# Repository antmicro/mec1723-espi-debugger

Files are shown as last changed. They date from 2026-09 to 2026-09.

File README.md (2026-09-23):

# MEC1723 eSPI Debugger

Copyright (c) 2026 [Antmicro](https://www.antmicro.com)

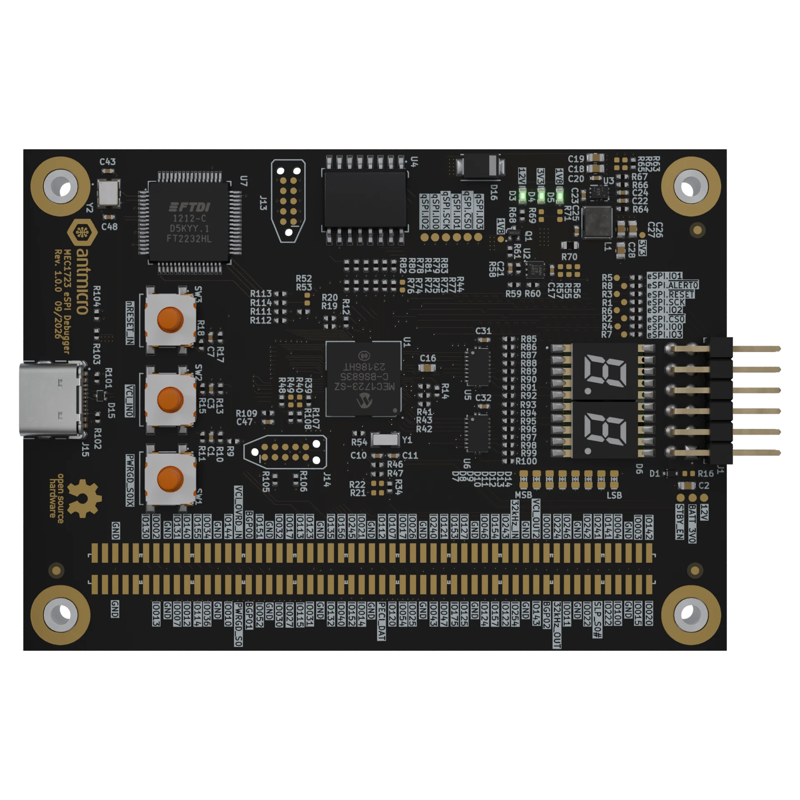
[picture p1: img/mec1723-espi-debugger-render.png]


## Overview

This project contains open hardware design files for a debug board based on Microchip MEC1723 embedded controller which includes ARM Cortex-M4 core and eSPI physical interface.
The board is designed to aid development, bring-up and integration of eSPI-based data link between servers (HPMs) and Data Center Secure Control Modules (DC-SCMs).
The board has a 0.1 inch pin header connector which allows to connect it to the eSPI bus in the system under development.
The board provides USB-accessible UART and JTAG interfaces, Port 80 status display and local flash storage for the MEC1723 firmware.
MEC1723 controllers are supported in [Zephyr](https://www.zephyrproject.org/) RTOS

The PCB design files were prepared in KiCad 10.x.

## Key features

* Microchip [MEC1723](https://www.microchip.com/en-us/product/mec1723) embedded controller with ARM Cortex-M4 and eSPI interface
* Generic 0.1 inch pinhead connector
* USB-C port with FTDI FT2232H USB interface bridge
* UART and JTAG interfaces accessible from the USB interface bridge
* 1 Gb QSPI NOR Flash for MEC1723 firmware storage
* Port 80 (POST code) display with dual seven-segment LED indicator
* Tag-Connect headers for debug and programming access
* 62 x 87 mm (2.44 x 3.42 inch) PCB outline

## Project structure

The main directory contains KiCad PCB project files, the LICENSE, and this README, and the img directory contains graphics for this README.

## License

This project is licensed under the [Apache-2.0](LICENSE) license.

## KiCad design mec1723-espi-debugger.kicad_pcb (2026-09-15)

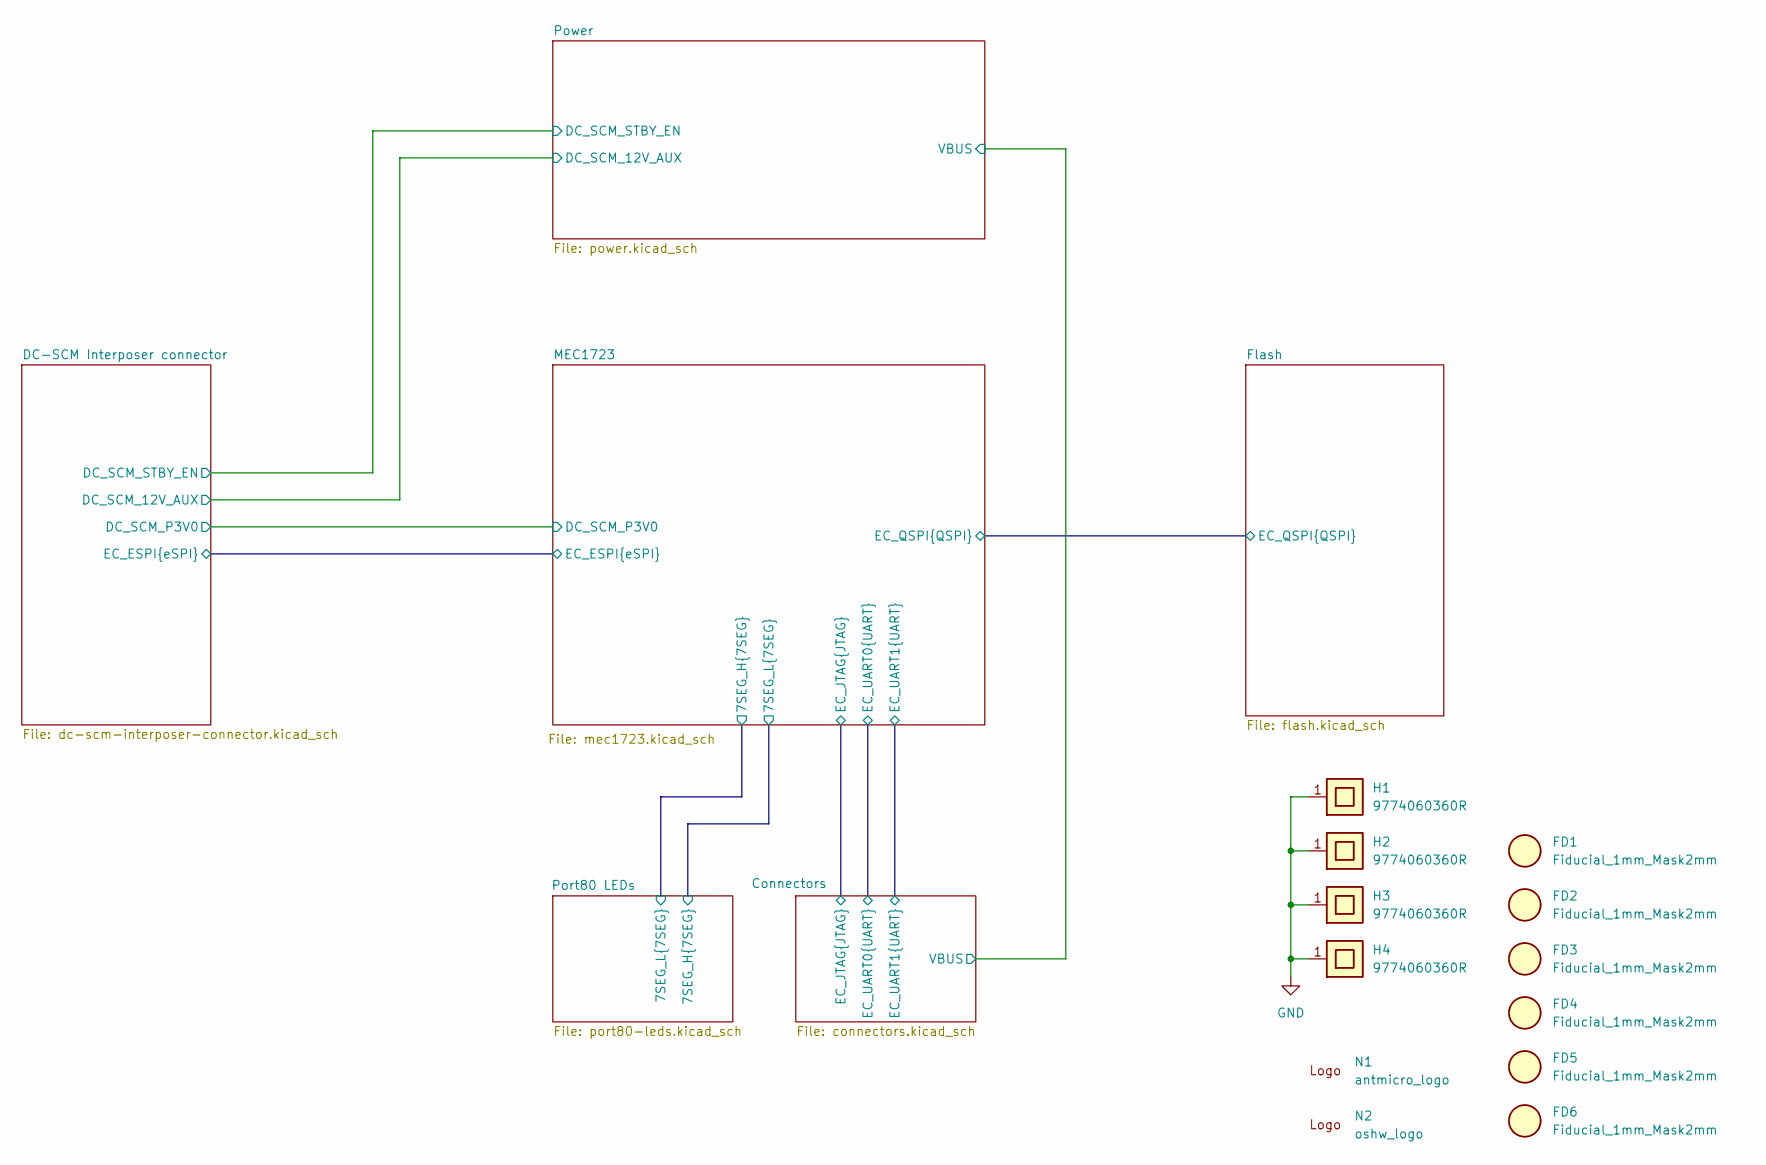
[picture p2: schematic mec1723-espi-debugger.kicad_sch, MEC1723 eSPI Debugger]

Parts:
FD1, FD2, FD3, FD4, FD5, FD6: Fiducial_1mm_Mask2mm
H1, H2, H3, H4: Spacer_Drill4.4mm_H6mm_9774060360R; MPN 9774060360R
N1: antmicro_logo; antmicro-logo_scaled_12mm
N2: oshw_logo; oshw-logo

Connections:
GND: H1.1, H2.1, H3.1, H4.1; also elsewhere on the board

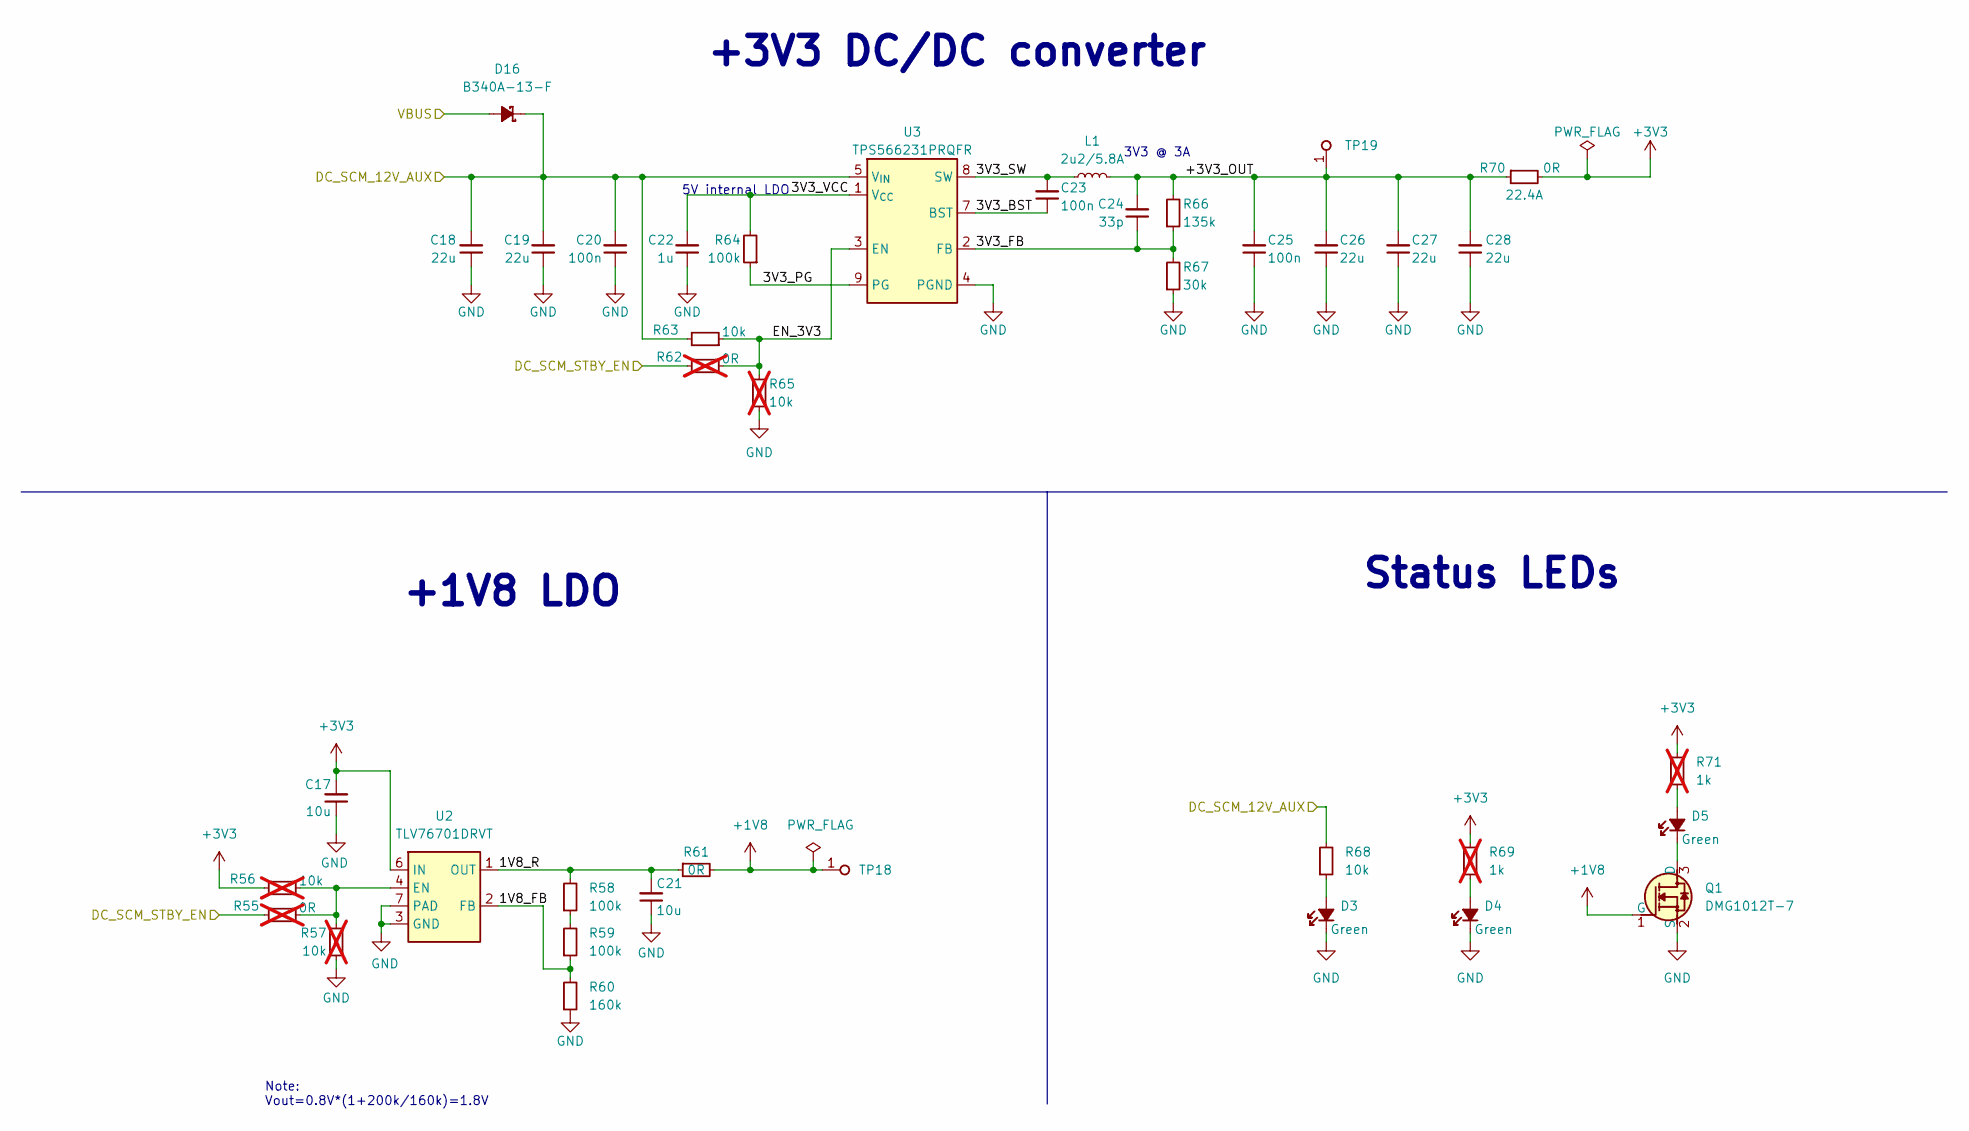
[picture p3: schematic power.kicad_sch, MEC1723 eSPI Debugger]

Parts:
C17, C21: C_10u_10V_0402; C_0402_1005Metric; Voltage 10V; MPN GRM155R61A106ME11D
C18, C19, C26, C27, C28: C_22u_16V_0603; C_0603_1608Metric_EIA; Voltage 16V; MPN CL10A226MO7JZNC
C20, C23, C25: C_100n_0402; C_0402_1005Metric; Voltage 50V; MPN GRM155R61H104KE14D
C22: C_1u_25V_0402; C_0402_1005Metric; Voltage 25V; MPN GRM155R61E105KE11J
C24: C_33p_0402; C_0402_1005Metric; MPN 04025A330FAT2A
D3, D4, D5: LED_G_0603_LTST-C190GKT; LED_0603_1608Metric_G; MPN LTST-C190GKT
D16: B340A-13-F; D_SMA; MPN B340A-13-F
L1: L_2u2_5.8A_WE-PMFI-35329222; L_WE-PMFI-353220; MPN 74479335329222
Q1: DMG1012T-7; SOT-523; MPN DMG1012T-7
R55, R62: R_0R_0402; R_0402_1005Metric; MPN ERJ2GE0R00X; not fitted
R56, R57, R65: R_10k_0402; R_0402_1005Metric; Tolerance 1%; MPN CR0402-FX-1002GLF; not fitted
R58, R59, R64: R_100k_0402; R_0402_1005Metric; Tolerance 1%; MPN CR0402-FX-1003GLF
R60: R_160k_0402; R_0402_1005Metric; Tolerance 1%; MPN CR0402-FX-1603GLF
R61: R_0R_0402; R_0402_1005Metric; MPN ERJ2GE0R00X
R63, R68: R_10k_0402; R_0402_1005Metric; Tolerance 1%; MPN CR0402-FX-1002GLF
R66: R_135k_0402; R_0402_1005Metric; Tolerance 0.1%; MPN RT0805BRD07135KL
R67: R_30k_0402; R_0402_1005Metric; Tolerance 1%; MPN CR0402-FX-3002GLF
R69, R71: R_1k_0402; R_0402_1005Metric; Tolerance 1%; MPN CR0402-FX-1001GLF; not fitted
R70: R_0R_22.4A_0603; R_0603_1608Metric; Tolerance template_tolerance; MPN PMR03EZPJ000
TP18, TP19: TP_0.75mm_SMD; TP_SMD_0.75mm
U2: TLV76701_WSON; WSON-6-1EP_2x2mm_P0.65mm; MPN TLV76701DRVT
U3: TPS566231P; VQFN-HR-9_2x1.5mm; MPN TPS566231PRQFR

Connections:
+1V8: Q1.1 (G), R61.2, TP18.1 (1_1); also elsewhere on the board
+3V3: C17.2, R56.2, R69.2, R70.2, R71.2, U2.6 (IN); also elsewhere on the board
/Connectors/VBUS: D16.2 (A); also elsewhere on the board
/DC-SCM Interposer connector/DC_SCM_12V_AUX: C18.2, C19.2, C20.2, D16.1 (C), R63.2, R68.2, U3.5 (V_{IN}), U3.6 (V_{IN}); also elsewhere on the board
/DC-SCM Interposer connector/DC_SCM_STBY_EN: R55.1, R62.1; also elsewhere on the board
/Power/1V8_FB: R59.1, R60.2, U2.2 (FB)
/Power/1V8_R: C21.2, R58.2, R61.1, U2.1 (OUT)
/Power/3V3_BST: C23.1, U3.7 (BST)
/Power/3V3_FB: C24.1, R66.1, R67.2, U3.2 (FB)
/Power/3V3_PG: R64.1, U3.9 (PG)
/Power/3V3_SW: C23.2, L1.1, U3.8 (SW)
/Power/3V3_VCC: C22.2, R64.2, U3.1 (V_{CC})
/Power/+3V3_OUT: C24.2, C25.2, C26.2, C27.2, C28.2, L1.2, R66.2, R70.1, TP19.1 (1_1)
/Power/EN_3V3: R62.2, R63.1, R65.2, U3.3 (EN)
GND: C17.1, C18.1, C19.1, C20.1, C21.1, C22.1, C25.1, C26.1, C27.1, C28.1, D3.1 (C), D4.1 (C), Q1.2 (S), R57.1, R60.1, R65.1, R67.1, U2.3 (GND), U2.5 (GND), U2.7 (PAD), U3.4 (PGND); also elsewhere on the board
unnamed: D3.2 (A), R68.1
unnamed: D4.2 (A), R69.1
unnamed: D5.2 (A), R71.1
unnamed: D5.1 (C), Q1.3 (D)
unnamed: R58.1, R59.2
unnamed: R55.2, R56.1, R57.2, U2.4 (EN)

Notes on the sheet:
Note: Vout=0.8V*(1+200k/160k)=1.8V
Status LEDs
+1V8 LDO
3V3 @ 3A
5V internal LDO
+3V3 DC/DC converter

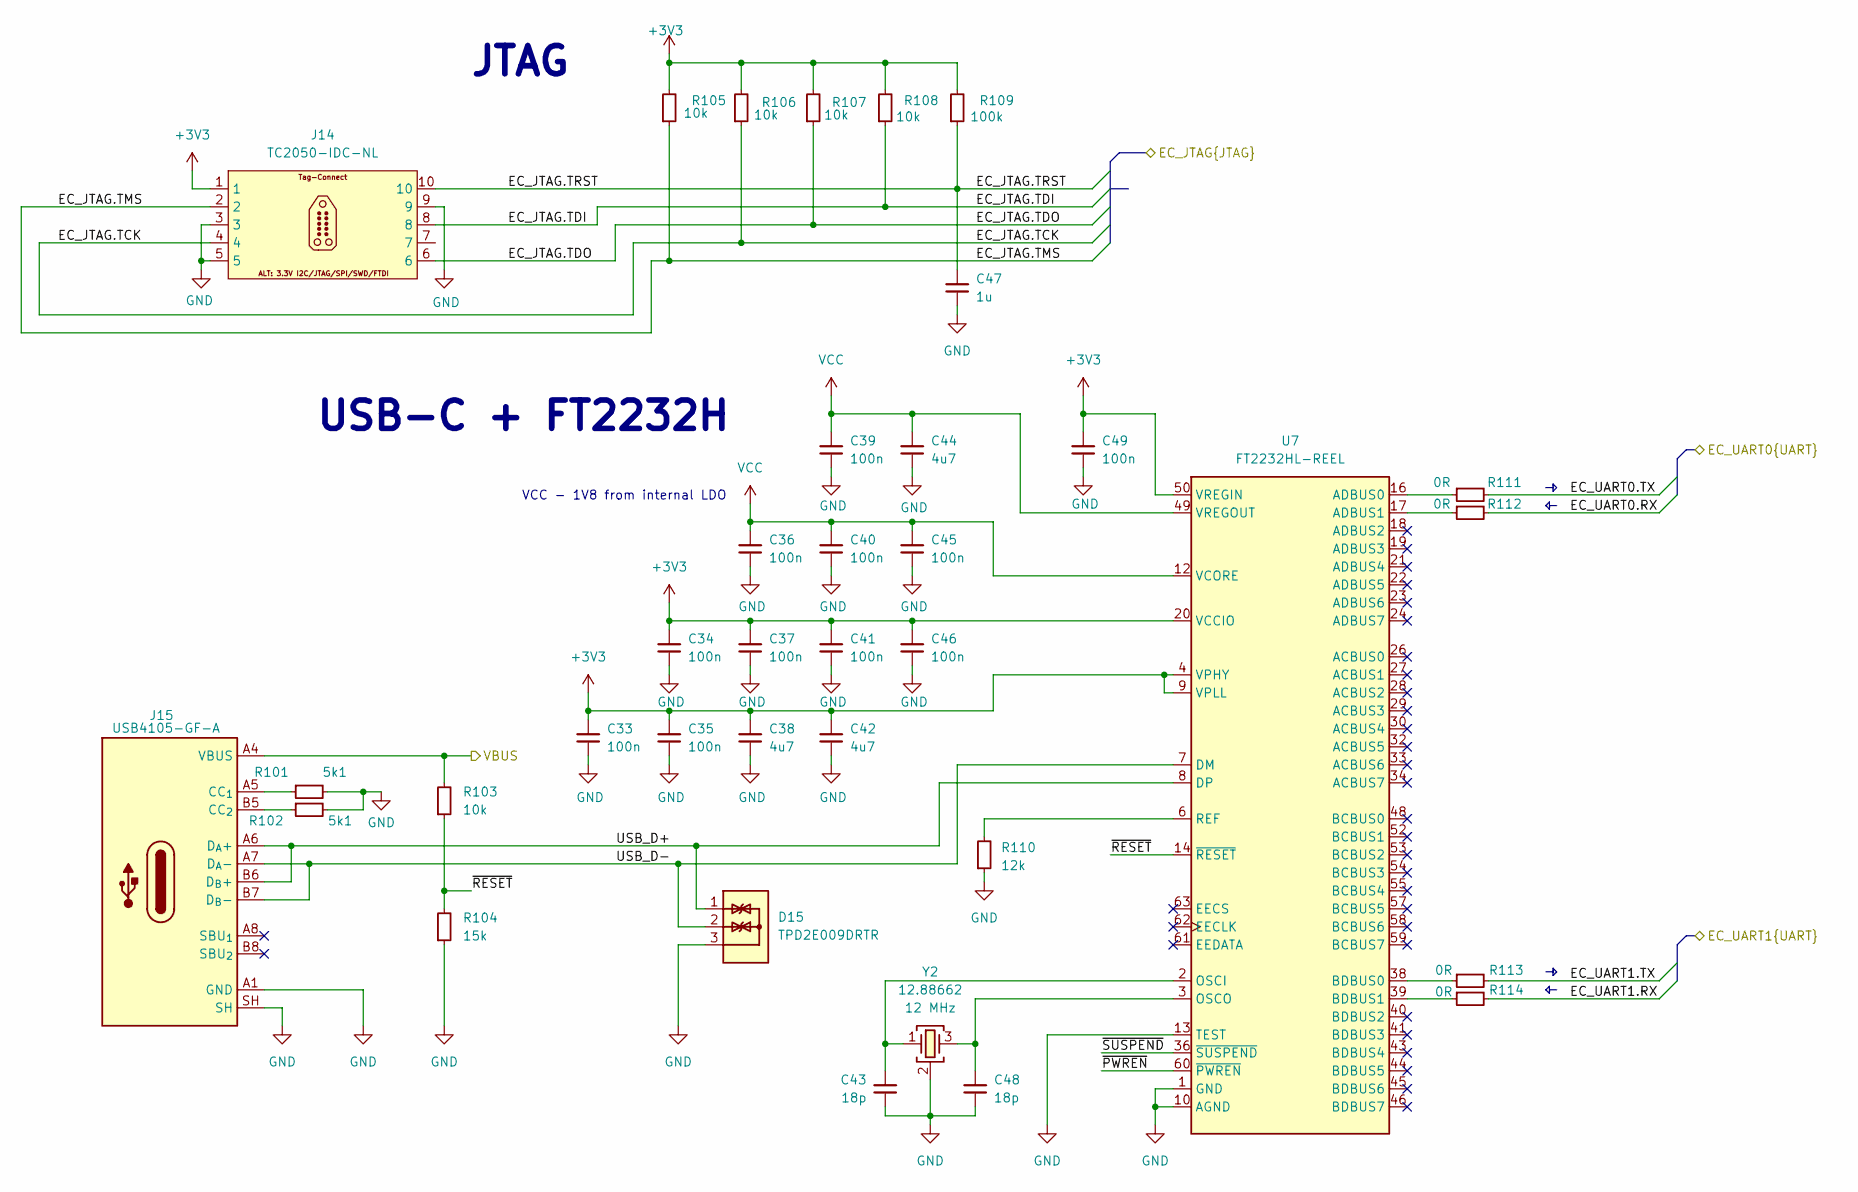
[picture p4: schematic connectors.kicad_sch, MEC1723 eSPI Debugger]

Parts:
C33, C34, C35, C36, C37, C39, C40, C41, C45, C46, C49: C_100n_16V_X7R_0402; C_0402_1005Metric; Voltage 16V; MPN C0402C104J4RAC7411
C38, C42, C44: C_4u7_10V_X7T_0402; C_0402_1005Metric; Voltage 10V; MPN GRM155D71A475ME15D
C43, C48: C_18p_0402; C_0402_1005Metric; MPN CL05C180JB51PNC
C47: C_1u_0402; C_0402_1005Metric; MPN C1005X6S1A105K050BC
D15: TPD2E009_SOT-9X3; SOT-723; MPN TPD2E009DRTR
J14: Tag-Connect_TC2050-IDC-NL_2x5_P1.27mm; MPN TC2050-IDC-NL
J15: USB-C_GCT_USB4105-GF-A; USB-C_Receptacle_GCT_USB4105-GF-A; MPN USB4105-GF-A
R101, R102: R_5k1_0402; R_0402_1005Metric; Tolerance 1%; MPN CR0402-FX-5101GLF
R103, R105, R106, R107, R108: R_10k_0402; R_0402_1005Metric; Tolerance 1%; MPN CR0402-FX-1002GLF
R104: R_15k_0402; R_0402_1005Metric; Tolerance 1%; MPN CR0402-FX-1502GLF
R109: R_100k_0402; R_0402_1005Metric; Tolerance 1%; MPN CR0402-FX-1003GLF
R110: R_12k_0402; R_0402_1005Metric; Tolerance 1%; MPN CR0402-FX-1202GLF
R111, R112, R113, R114: R_0R_0402; R_0402_1005Metric; MPN ERJ2GE0R00X
U7: FT2232HL-REEL; LQFP-64_10x10mm_P0.5mm; MPN FT2232HL-REEL
Y2: Resonator_12MHz_KX-7; Resonator_SMD_Geyer_KX-7_3.2x2.5x0.8mm; MPN 12.88662

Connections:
+3V3: C33.2, C34.2, C35.2, C37.2, C38.2, C41.2, C42.2, C46.2, C49.2, J14.1, R105.2, R106.2, R107.2, R108.2, R109.2, U7.4 (VPHY), U7.9 (VPLL), U7.20 (VCCIO), U7.31 (VCCIO), U7.42 (VCCIO), U7.50 (VREGIN), U7.56 (VCCIO); also elsewhere on the board
/Connectors/EC_JTAG.TCK: J14.4, R106.1; also elsewhere on the board
/Connectors/EC_JTAG.TDI: J14.8, R108.1; also elsewhere on the board
/Connectors/EC_JTAG.TDO: J14.6, R107.1; also elsewhere on the board
/Connectors/EC_JTAG.TMS: J14.2, R105.1; also elsewhere on the board
/Connectors/EC_JTAG.TRST: C47.2, J14.10, R109.1; also elsewhere on the board
/Connectors/EC_UART0.RX: R112.2; also elsewhere on the board
/Connectors/EC_UART0.TX: R111.2; also elsewhere on the board
/Connectors/EC_UART1.RX: R114.2; also elsewhere on the board
/Connectors/EC_UART1.TX: R113.2; also elsewhere on the board
/Connectors/USB_D+: D15.1, J15.A6 (D_{A}+), J15.B6 (D_{B}+), U7.8 (DP)
/Connectors/USB_D-: D15.2, J15.A7 (D_{A}-), J15.B7 (D_{B}-), U7.7 (DM)
/Connectors/VBUS: J15.A4 (VBUS), J15.A9 (VBUS), J15.B4 (VBUS), J15.B9 (VBUS), R103.2; also elsewhere on the board
/Connectors/~PWREN: U7.60 (~PWREN)
/Connectors/~RESET: R103.1, R104.2, U7.14 (~RESET)
/Connectors/~SUSPEND: U7.36 (~SUSPEND)
GND: C33.1, C34.1, C35.1, C36.1, C37.1, C38.1, C39.1, C40.1, C41.1, C42.1, C43.1, C44.1, C45.1, C46.1, C47.1, C48.1, C49.1, D15.3, J14.3, J14.5, J14.9, J15.A1 (GND), J15.A12 (GND), J15.B1 (GND), J15.B12 (GND), J15.SH, R101.2, R102.2, R104.1, R110.1, U7.1 (GND), U7.5 (GND), U7.10 (AGND), U7.11 (GND), U7.13 (TEST), U7.15 (GND), U7.25 (GND), U7.35 (GND), U7.47 (GND), U7.51 (GND), Y2.2 (SH), Y2.4 (SH); also elsewhere on the board
unnamed: J15.A5 (CC_{1}), R101.1
unnamed: J15.B5 (CC_{2}), R102.1
unnamed: R111.1, U7.16 (ADBUS0)
unnamed: R112.1, U7.17 (ADBUS1)
unnamed: R113.1, U7.38 (BDBUS0)
unnamed: R114.1, U7.39 (BDBUS1)
unnamed: C43.2, U7.2 (OSCI), Y2.1
unnamed: C48.2, U7.3 (OSCO), Y2.3
unnamed: R110.2, U7.6 (REF)
VCC: C36.2, C39.2, C40.2, C44.2, C45.2, U7.12 (VCORE), U7.37 (VCORE), U7.49 (VREGOUT), U7.64 (VCORE)

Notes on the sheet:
VCC - 1V8 from internal LDO
JTAG
USB-C + FT2232H

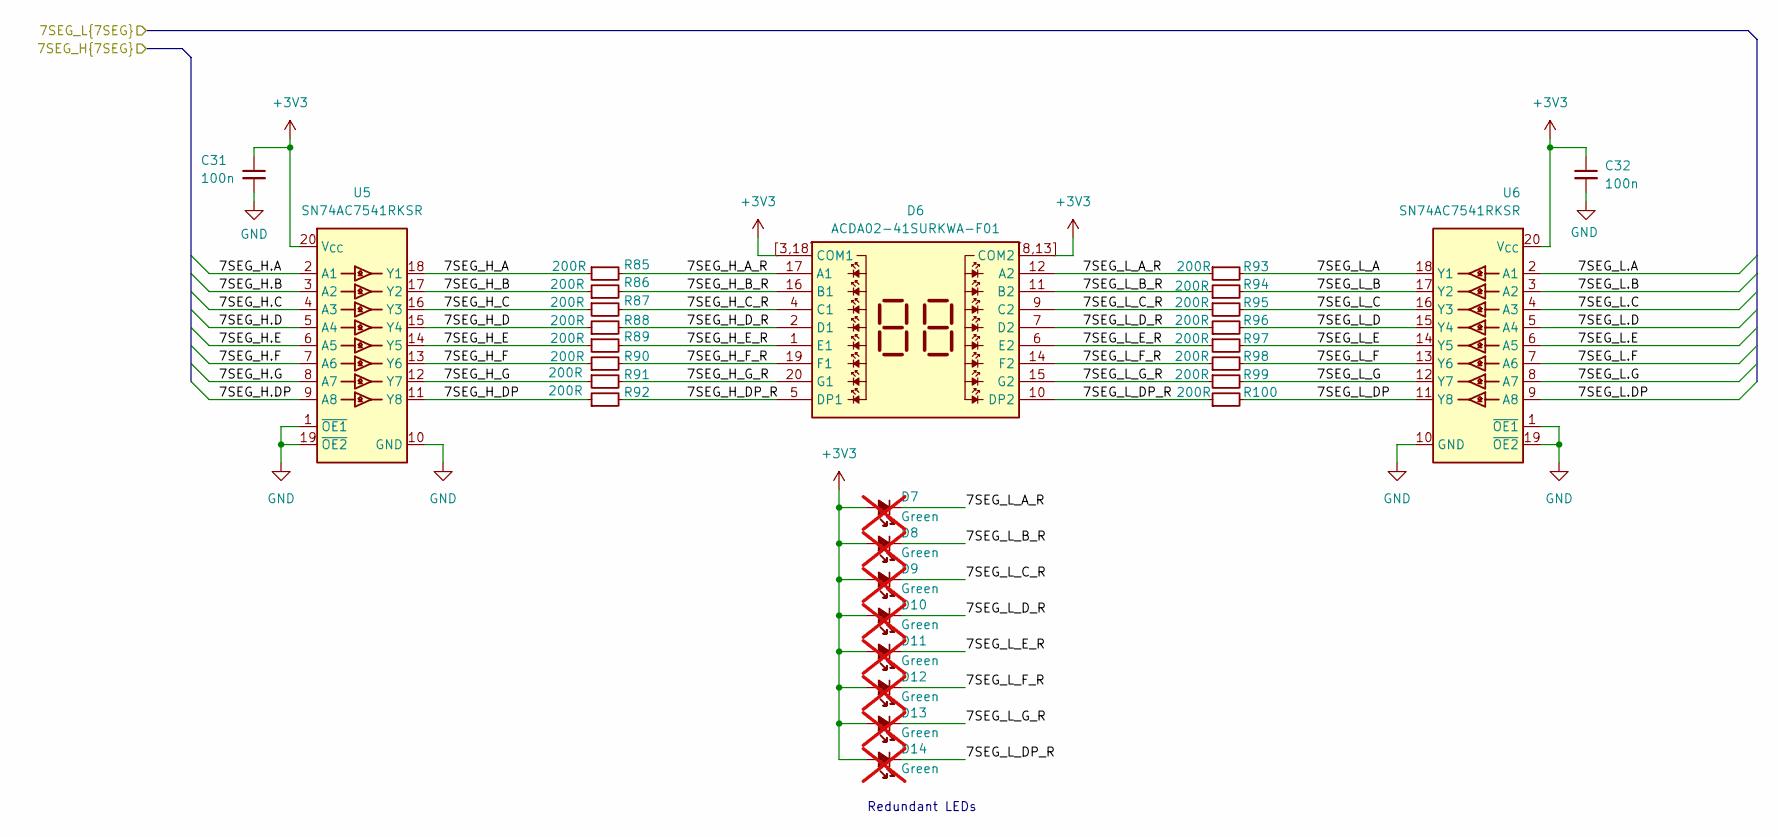
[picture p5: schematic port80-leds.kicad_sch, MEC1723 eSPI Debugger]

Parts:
C31, C32: C_100n_0402; C_0402_1005Metric; Voltage 50V; MPN GRM155R61H104KE14D
D6: ACDA02-41SURKWA-F01; MPN ACDA02-41SURKWA-F01
D7, D8, D9, D10, D11, D12, D13, D14: LED_G_0603_LTST-C190GKT; LED_0603_1608Metric_G; MPN LTST-C190GKT; not fitted
R85, R86, R87, R88, R89, R90, R91, R92, R93, R94, R95, R96, R97, R98, R99, R100: R_200R_0402; R_0402_1005Metric; Tolerance 1%; MPN CR0402-FX-2000GLF
U5, U6: SN74AC7541_VQFN; VQFN-20_1EP_4.5x2.5mm_P0.5mm; MPN SN74AC7541RKSR

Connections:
+3V3: C31.1, C32.1, D6.3 (COM1), D6.8 (COM2), D6.13 (COM2), D6.18 (COM1), D6.[3,18] (COM1), D6.[8,13] (COM2), D7.2 (A), D8.2 (A), D9.2 (A), D10.2 (A), D11.2 (A), D12.2 (A), D13.2 (A), D14.2 (A), U5.20 (V_{CC}), U6.20 (V_{CC}); also elsewhere on the board
/MEC1723/7SEG_H.A: U6.2 (A1); also elsewhere on the board
/MEC1723/7SEG_H.B: U6.3 (A2); also elsewhere on the board
/MEC1723/7SEG_H.C: U6.4 (A3); also elsewhere on the board
/MEC1723/7SEG_H.D: U6.5 (A4); also elsewhere on the board
/MEC1723/7SEG_H.DP: U6.9 (A8); also elsewhere on the board
/MEC1723/7SEG_H.E: U6.6 (A5); also elsewhere on the board
/MEC1723/7SEG_H.F: U6.7 (A6); also elsewhere on the board
/MEC1723/7SEG_H.G: U6.8 (A7); also elsewhere on the board
/MEC1723/7SEG_L.A: U5.2 (A1); also elsewhere on the board
/MEC1723/7SEG_L.B: U5.3 (A2); also elsewhere on the board
/MEC1723/7SEG_L.C: U5.4 (A3); also elsewhere on the board
/MEC1723/7SEG_L.D: U5.5 (A4); also elsewhere on the board
/MEC1723/7SEG_L.DP: U5.9 (A8); also elsewhere on the board
/MEC1723/7SEG_L.E: U5.6 (A5); also elsewhere on the board
/MEC1723/7SEG_L.F: U5.7 (A6); also elsewhere on the board
/MEC1723/7SEG_L.G: U5.8 (A7); also elsewhere on the board
/Port80 LEDs/7SEG_H_A: R85.1, U5.18 (Y1)
/Port80 LEDs/7SEG_H_A_R: D6.17 (A1), R85.2
/Port80 LEDs/7SEG_H_B: R86.1, U5.17 (Y2)
/Port80 LEDs/7SEG_H_B_R: D6.16 (B1), R86.2
/Port80 LEDs/7SEG_H_C: R87.1, U5.16 (Y3)
/Port80 LEDs/7SEG_H_C_R: D6.4 (C1), R87.2
/Port80 LEDs/7SEG_H_D: R88.1, U5.15 (Y4)
/Port80 LEDs/7SEG_H_DP: R92.1, U5.11 (Y8)
/Port80 LEDs/7SEG_H_DP_R: D6.5 (DP1), R92.2
/Port80 LEDs/7SEG_H_D_R: D6.2 (D1), R88.2
/Port80 LEDs/7SEG_H_E: R89.1, U5.14 (Y5)
/Port80 LEDs/7SEG_H_E_R: D6.1 (E1), R89.2
/Port80 LEDs/7SEG_H_F: R90.1, U5.13 (Y6)
/Port80 LEDs/7SEG_H_F_R: D6.19 (F1), R90.2
/Port80 LEDs/7SEG_H_G: R91.1, U5.12 (Y7)
/Port80 LEDs/7SEG_H_G_R: D6.20 (G1), R91.2
/Port80 LEDs/7SEG_L_A: R93.2, U6.18 (Y1)
/Port80 LEDs/7SEG_L_A_R: D6.12 (A2), D7.1 (C), R93.1
/Port80 LEDs/7SEG_L_B: R94.2, U6.17 (Y2)
/Port80 LEDs/7SEG_L_B_R: D6.11 (B2), D8.1 (C), R94.1
/Port80 LEDs/7SEG_L_C: R95.2, U6.16 (Y3)
/Port80 LEDs/7SEG_L_C_R: D6.9 (C2), D9.1 (C), R95.1
/Port80 LEDs/7SEG_L_D: R96.2, U6.15 (Y4)
/Port80 LEDs/7SEG_L_DP: R100.2, U6.11 (Y8)
/Port80 LEDs/7SEG_L_DP_R: D6.10 (DP2), D14.1 (C), R100.1
/Port80 LEDs/7SEG_L_D_R: D6.7 (D2), D10.1 (C), R96.1
/Port80 LEDs/7SEG_L_E: R97.2, U6.14 (Y5)
/Port80 LEDs/7SEG_L_E_R: D6.6 (E2), D11.1 (C), R97.1
/Port80 LEDs/7SEG_L_F: R98.2, U6.13 (Y6)
/Port80 LEDs/7SEG_L_F_R: D6.14 (F2), D12.1 (C), R98.1
/Port80 LEDs/7SEG_L_G: R99.2, U6.12 (Y7)
/Port80 LEDs/7SEG_L_G_R: D6.15 (G2), D13.1 (C), R99.1
GND: C31.2, C32.2, U5.1 (~OE1), U5.10 (GND), U5.19 (~OE2), U5.21 (GND), U6.1 (~OE1), U6.10 (GND), U6.19 (~OE2), U6.21 (GND); also elsewhere on the board

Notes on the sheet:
Redundant LEDs

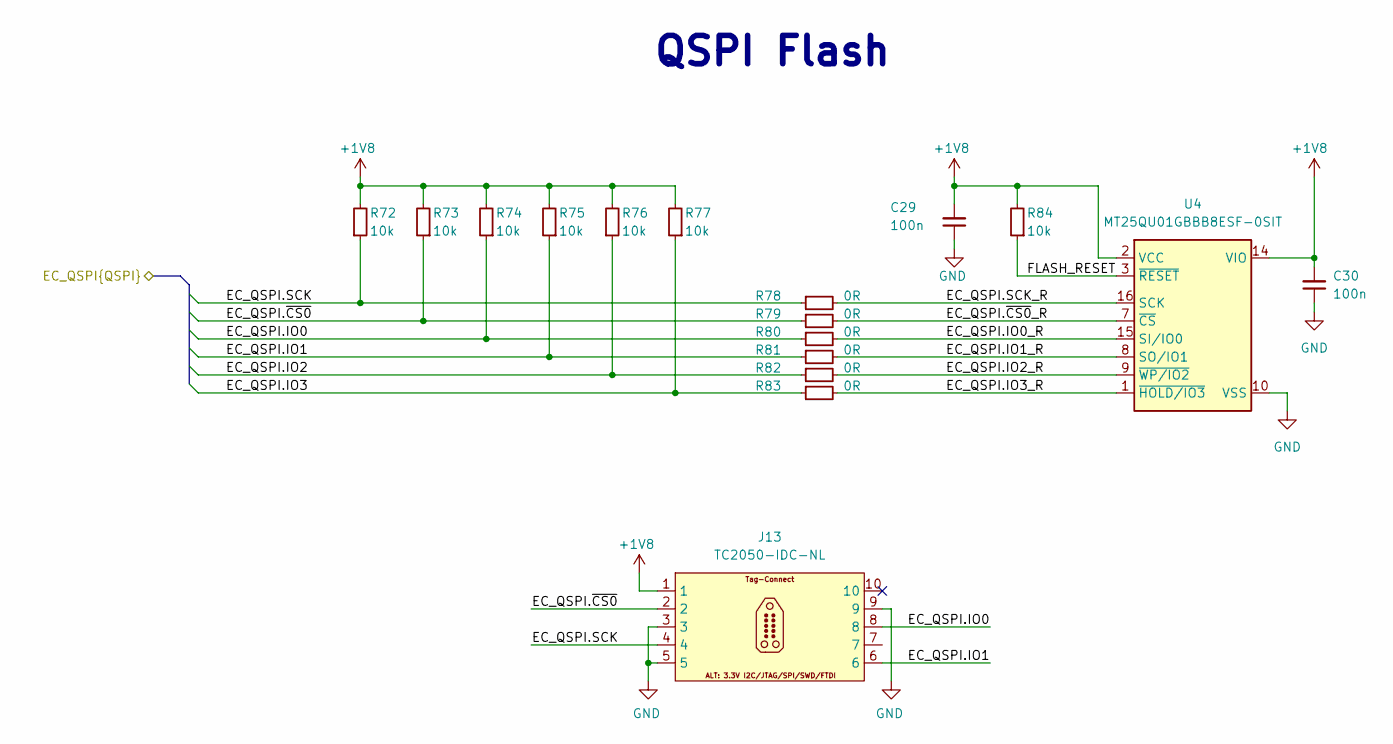
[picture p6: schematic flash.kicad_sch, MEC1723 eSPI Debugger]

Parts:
C29, C30: C_100n_0402; C_0402_1005Metric; Voltage 50V; MPN GRM155R61H104KE14D
J13: Tag-Connect_TC2050-IDC-NL_2x5_P1.27mm; MPN TC2050-IDC-NL
R72, R73, R74, R75, R76, R77, R84: R_10k_0402; R_0402_1005Metric; Tolerance 1%; MPN CR0402-FX-1002GLF
R78, R79, R80, R81, R82, R83: R_0R_0402; R_0402_1005Metric; MPN ERJ2GE0R00X
U4: MT25QU01GBBB8_SOIC; SOIC-16_W7.5mm; MPN MT25QU01GBBB8ESF-0SIT

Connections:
+1V8: C29.2, C30.2, J13.1, R72.2, R73.2, R74.2, R75.2, R76.2, R77.2, R84.2, U4.2 (VCC), U4.14 (VIO); also elsewhere on the board
/Flash/EC_QSPI.IO0: J13.8, R74.1, R80.1; also elsewhere on the board
/Flash/EC_QSPI.IO0_R: R80.2, U4.15 (SI/IO0)
/Flash/EC_QSPI.IO1: J13.6, R75.1, R81.1; also elsewhere on the board
/Flash/EC_QSPI.IO1_R: R81.2, U4.8 (SO/IO1)
/Flash/EC_QSPI.IO2: R76.1, R82.1; also elsewhere on the board
/Flash/EC_QSPI.IO2_R: R82.2, U4.9 (~WP/IO2)
/Flash/EC_QSPI.IO3: R77.1, R83.1; also elsewhere on the board
/Flash/EC_QSPI.IO3_R: R83.2, U4.1 (~HOLD/IO3)
/Flash/EC_QSPI.SCK: J13.4, R72.1, R78.1; also elsewhere on the board
/Flash/EC_QSPI.SCK_R: R78.2, U4.16 (SCK)
/Flash/EC_QSPI.~CS0: J13.2, R73.1, R79.1; also elsewhere on the board
/Flash/EC_QSPI.~CS0_R: R79.2, U4.7 (~CS)
/Flash/FLASH_RESET: R84.1, U4.3 (~RESET)
GND: C29.1, C30.1, J13.3, J13.5, J13.9, U4.10 (VSS); also elsewhere on the board

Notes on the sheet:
QSPI Flash

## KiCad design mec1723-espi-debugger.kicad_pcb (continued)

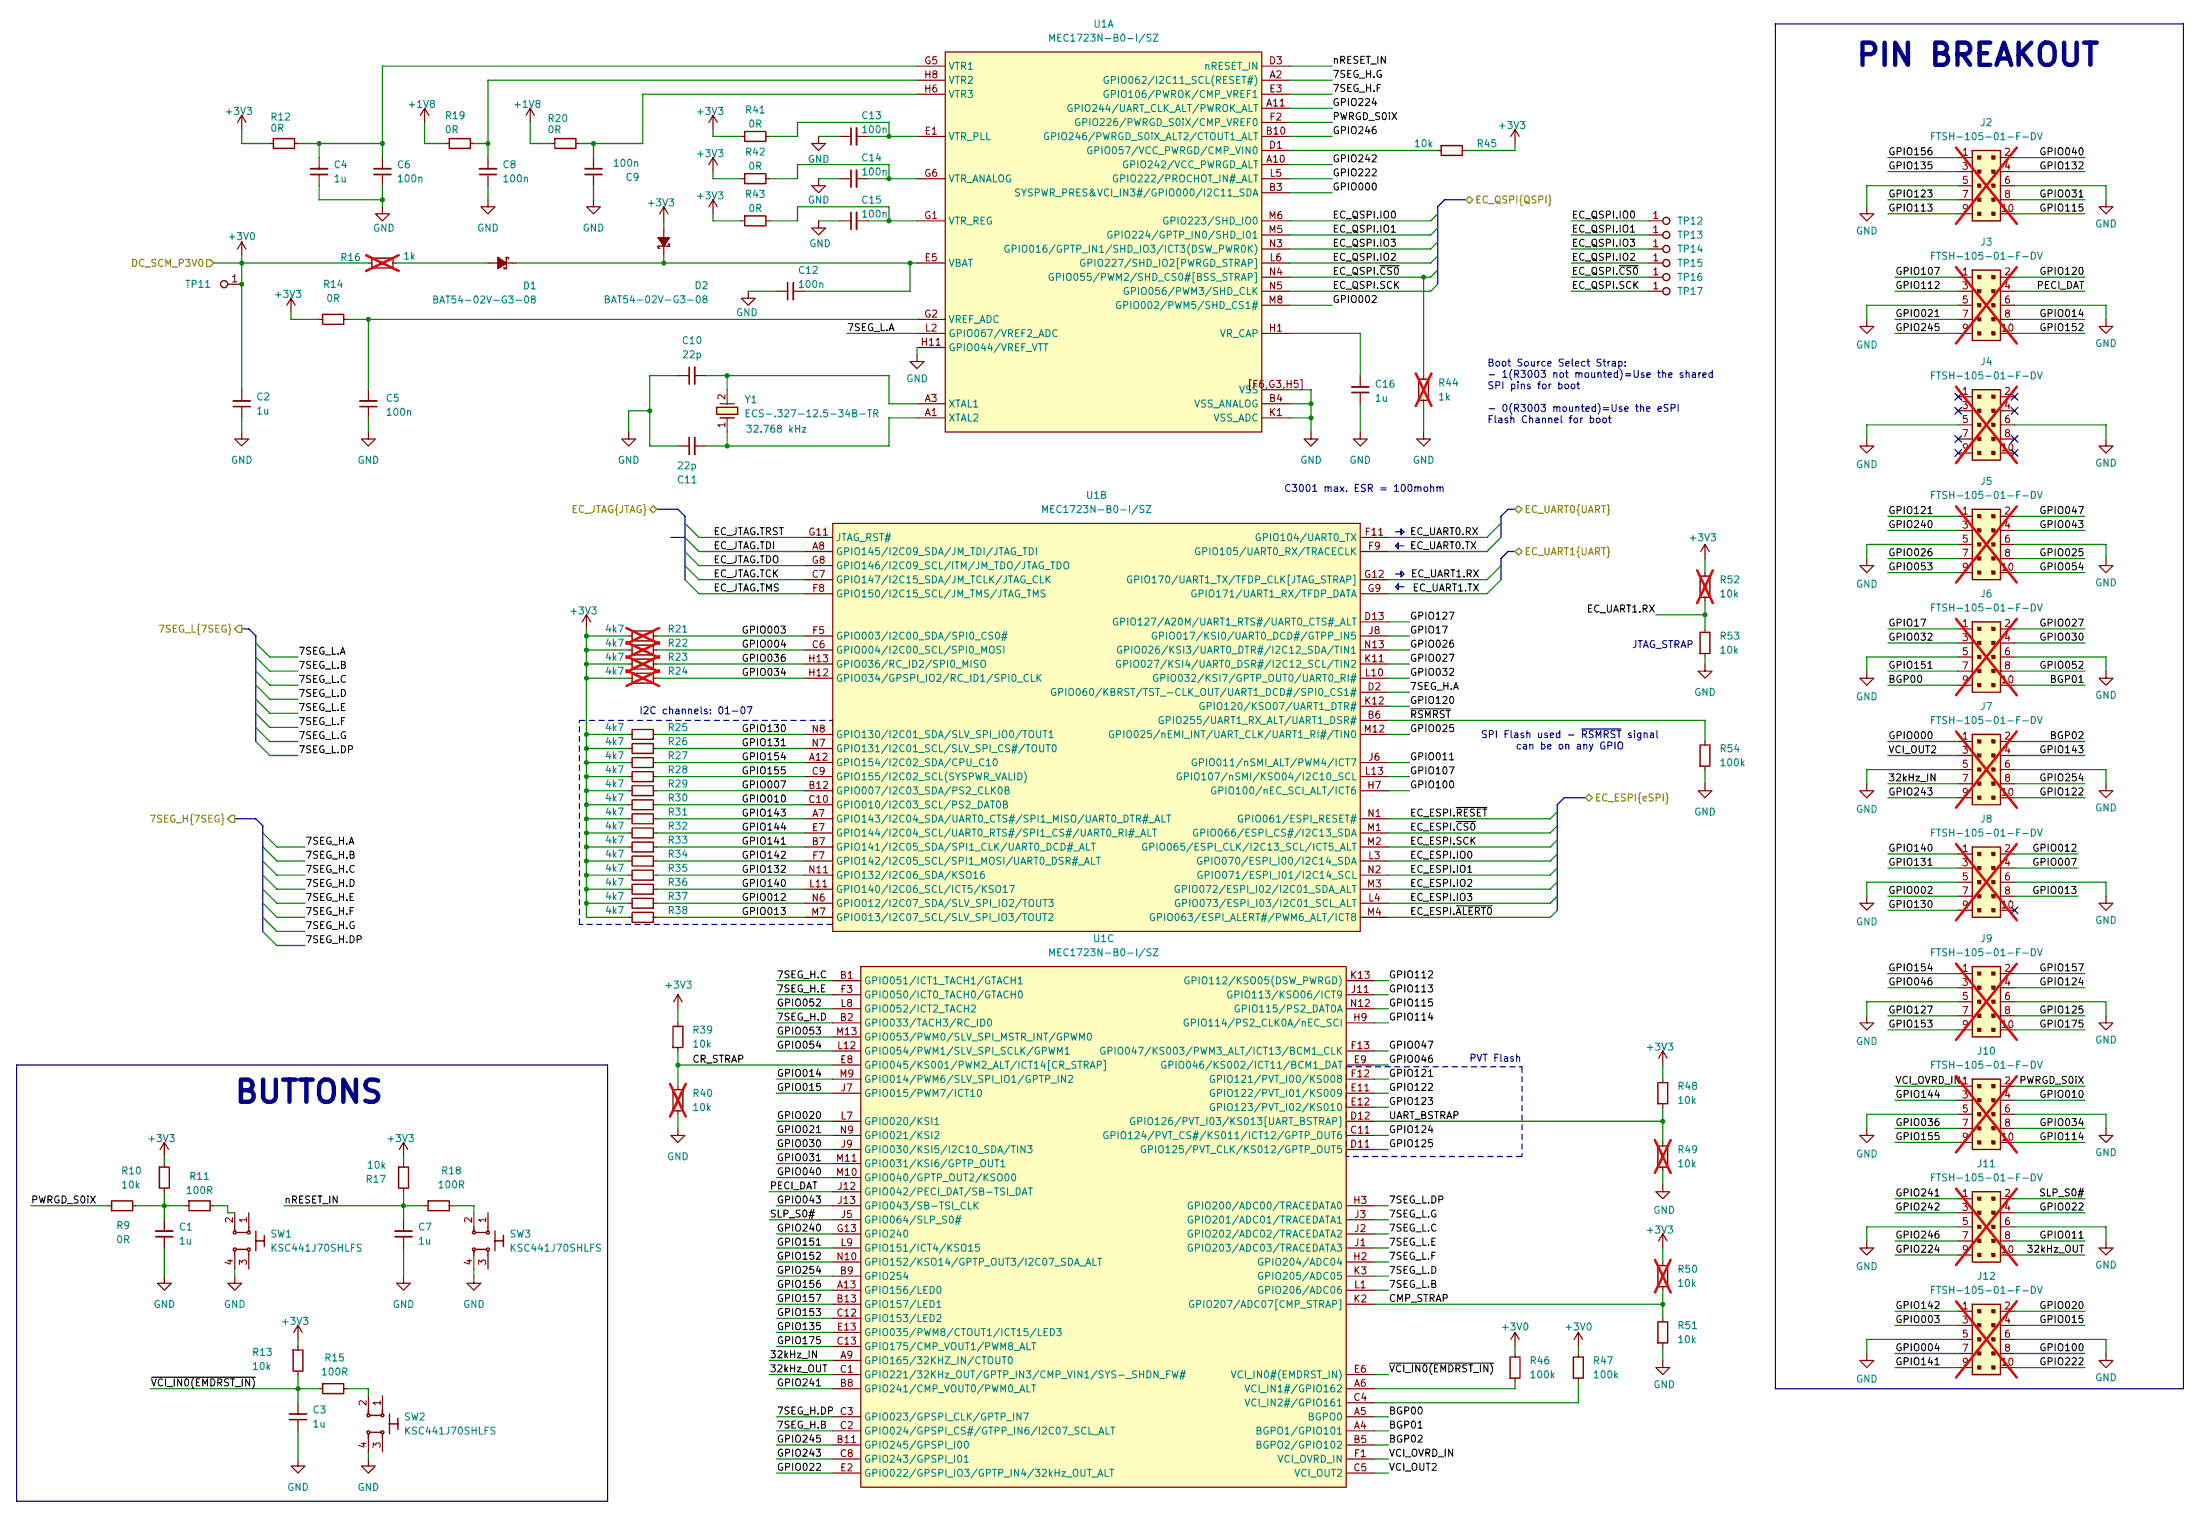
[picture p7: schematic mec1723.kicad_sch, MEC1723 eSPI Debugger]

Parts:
C1, C3, C7: C_1u_6.3V_X6S_0402; C_0402_1005Metric; Voltage 6.3V; MPN GRT155C80J105KE01D
C2, C4, C16: C_1u_0603; C_0603_1608Metric; MPN 0603YD105KAT2A
C5, C9, C12, C13, C14, C15: C_100n_0402; C_0402_1005Metric; Voltage 50V; MPN GRM155R61H104KE14D
C6, C8: C_100n_16V_X7R_0402; C_0402_1005Metric; Voltage 16V; MPN C0402C104J4RAC7411
C10, C11: C_22p_0402; C_0402_1005Metric; MPN CC0402JRNPO9BN220
D1, D2: BAT54-02V-G3-08; SOD-523; MPN BAT54-02V-G3-08
J2, J3, J4, J5, J6, J7, J8, J9, J10, J11, J12: PinHeader_2x5_P1.27mm_SMD; MPN FTSH-105-01-F-DV; not fitted
R9, R12, R14, R19, R20, R41, R42, R43: R_0R_0402; R_0402_1005Metric; MPN ERJ2GE0R00X
R10, R13, R17, R39, R45, R48, R51, R53: R_10k_0402; R_0402_1005Metric; Tolerance 1%; MPN CR0402-FX-1002GLF
R11, R15, R18: R_100R_0402; R_0402_1005Metric; Tolerance 1%; MPN CR0402-FX-1000GLF
R16, R44: R_1k_0402; R_0402_1005Metric; Tolerance 1%; MPN CR0402-FX-1001GLF; not fitted
R21, R22, R23, R24: R_4k7_0402; R_0402_1005Metric; Tolerance 1%; MPN CR0402-FX-4701GLF; not fitted
R25, R26, R27, R28, R29, R30, R31, R32, R33, R34, R35, R36, R37, R38: R_4k7_0402; R_0402_1005Metric; Tolerance 1%; MPN CR0402-FX-4701GLF
R40, R49, R50, R52: R_10k_0402; R_0402_1005Metric; Tolerance 1%; MPN CR0402-FX-1002GLF; not fitted
R46, R47, R54: R_100k_0402; R_0402_1005Metric; Tolerance 1%; MPN CR0402-FX-1003GLF
SW1, SW2, SW3: SW_KSC441J70SHLFS_SMD; MPN KSC441J70SHLFS
TP11, TP12, TP13, TP14, TP15, TP16, TP17: TP_1mm_SMD; TP_SMD_1mm
U1: MEC1723N-B0-I/SZ; BGA-169-144_9x9mm_Layout13x13_P0.7mm; MPN MEC1723N-B0-I/SZ
Y1: Resonator_32.768kHz_ECX-31B; Resonator_SMD_ECS_ECX-31B_3.2x1.5x0.9mm; MPN ECS-.327-12.5-34B-TR

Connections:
+1V8: R19.1, R20.1; also elsewhere on the board
+3V0: C2.2, R16.1, R46.2, R47.2, TP11.1 (1_1); also elsewhere on the board
+3V3: D2.2 (A), R10.1, R12.1, R13.1, R14.1, R17.1, R21.2, R22.2, R23.2, R24.2, R25.2, R26.2, R27.2, R28.2, R29.2, R30.2, R31.2, R32.2, R33.2, R34.2, R35.2, R36.2, R37.2, R38.2, R39.2, R41.1, R42.1, R43.1, R45.2, R48.2, R50.2, R52.2; also elsewhere on the board
/Connectors/EC_JTAG.TCK: U1.C7 (GPIO147/I2C15_SDA/JM_TCLK/JTAG_CLK); also elsewhere on the board
/Connectors/EC_JTAG.TDI: U1.A8 (GPIO145/I2C09_SDA/JM_TDI/JTAG_TDI); also elsewhere on the board
/Connectors/EC_JTAG.TDO: U1.G8 (GPIO146/I2C09_SCL/ITM/JM_TDO/JTAG_TDO); also elsewhere on the board
/Connectors/EC_JTAG.TMS: U1.F8 (GPIO150/I2C15_SCL/JM_TMS/JTAG_TMS); also elsewhere on the board
/Connectors/EC_JTAG.TRST: U1.G11 (JTAG_RST#); also elsewhere on the board
/Connectors/EC_UART0.RX: U1.F11 (GPIO104/UART0_TX); also elsewhere on the board
/Connectors/EC_UART0.TX: U1.F9 (GPIO105/UART0_RX/TRACECLK); also elsewhere on the board
/Connectors/EC_UART1.RX: R52.1, R53.2, U1.G12 (GPIO170/UART1_TX/TFDP_CLK[JTAG_STRAP]); also elsewhere on the board
/Connectors/EC_UART1.TX: U1.G9 (GPIO171/UART1_RX/TFDP_DATA); also elsewhere on the board
/DC-SCM Interposer connector/EC_ESPI.IO0: U1.L3 (GPIO070/ESPI_I00/I2C14_SDA); also elsewhere on the board
/DC-SCM Interposer connector/EC_ESPI.IO1: U1.N2 (GPIO071/ESPI_I01/I2C14_SCL); also elsewhere on the board
/DC-SCM Interposer connector/EC_ESPI.IO2: U1.M3 (GPIO072/ESPI_I02/I2C01_SDA_ALT); also elsewhere on the board
/DC-SCM Interposer connector/EC_ESPI.IO3: U1.L4 (GPIO073/ESPI_I03/I2C01_SCL_ALT); also elsewhere on the board
/DC-SCM Interposer connector/EC_ESPI.SCK: U1.M2 (GPIO065/ESPI_CLK/I2C13_SCL/ICT5_ALT); also elsewhere on the board
/DC-SCM Interposer connector/EC_ESPI.~ALERT0: U1.M4 (GPIO063/ESPI_ALERT#/PWM6_ALT/ICT8); also elsewhere on the board
/DC-SCM Interposer connector/EC_ESPI.~CS0: U1.M1 (GPIO066/ESPI_CS#/I2C13_SDA); also elsewhere on the board
/DC-SCM Interposer connector/EC_ESPI.~RESET: U1.N1 (GPIO061/ESPI_RESET#); also elsewhere on the board
/Flash/EC_QSPI.IO0: TP12.1 (1_1), U1.M6 (GPIO223/SHD_IO0); also elsewhere on the board
/Flash/EC_QSPI.IO1: TP13.1 (1_1), U1.M5 (GPIO224/GPTP_IN0/SHD_I01); also elsewhere on the board
/Flash/EC_QSPI.IO2: TP15.1 (1_1), U1.L6 (GPIO227/SHD_IO2[PWRGD_STRAP]); also elsewhere on the board
/Flash/EC_QSPI.IO3: TP14.1 (1_1), U1.N3 (GPIO016/GPTP_IN1/SHD_IO3/ICT3(DSW_PWR0K)); also elsewhere on the board
/Flash/EC_QSPI.SCK: TP17.1 (1_1), U1.N5 (GPIO056/PWM3/SHD_CLK); also elsewhere on the board
/Flash/EC_QSPI.~CS0: R44.2, TP16.1 (1_1), U1.N4 (GPIO055/PWM2/SHD_CS0#[BSS_STRAP]); also elsewhere on the board
/MEC1723/7SEG_H.A: U1.D2 (GPIO060/KBRST/TST_-CLK_OUT/UART1_DCD#/S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); also elsewhere on the board
/MEC1723/7SEG_H.B: U1.C2 (GPIO024/GPSPI_CS#/GTPP_IN6/I2C07_SCL_ALT); also elsewhere on the board
/MEC1723/7SEG_H.C: U1.B1 (GPIO051/ICT1_TACH1/GTACH1); also elsewhere on the board
/MEC1723/7SEG_H.D: U1.B2 (GPIO033/TACH3/RC_ID0); also elsewhere on the board
/MEC1723/7SEG_H.DP: U1.C3 (GPIO023/GPSPI_CLK/GPTP_IN7); also elsewhere on the board
/MEC1723/7SEG_H.E: U1.F3 (GPIO050/ICT0_TACH0/GTACH0); also elsewhere on the board
/MEC1723/7SEG_H.F: U1.E3 (GPIO106/PWROK/CMP_VREF1); also elsewhere on the board
/MEC1723/7SEG_H.G: U1.A2 (GPIO062/I2C11_SCL(RESET#)); also elsewhere on the board
/MEC1723/7SEG_L.A: U1.L2 (GPIO067/VREF2_ADC); also elsewhere on the board
/MEC1723/7SEG_L.B: U1.L1 (GPIO206/ADC06); also elsewhere on the board
/MEC1723/7SEG_L.C: U1.J2 (GPIO202/ADC02/TRACEDATA2); also elsewhere on the board
/MEC1723/7SEG_L.D: U1.K3 (GPIO205/ADC05); also elsewhere on the board
/MEC1723/7SEG_L.DP: U1.H3 (GPIO200/ADC00/TRACEDATA0); also elsewhere on the board
/MEC1723/7SEG_L.E: U1.J1 (GPIO203/ADC03/TRACEDATA3); also elsewhere on the board
/MEC1723/7SEG_L.F: U1.H2 (GPIO204/ADC04); also elsewhere on the board
/MEC1723/7SEG_L.G: U1.J3 (GPIO201/ADC01/TRACEDATA1); also elsewhere on the board
/MEC1723/32kHz_IN: J7.7, U1.A9 (GPIO165/32KHZ_IN/CTOUT0)
/MEC1723/32kHz_OUT: J11.10, U1.C1 (GPIO221/32KHz_OUT/GPTP_IN3/CMP_VIN1/SYS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)
/MEC1723/BGP00: J6.9, U1.A5 (BGPO0)
/MEC1723/BGP01: J6.10, U1.A4 (BGPO1/GPIO101)
/MEC1723/BGP02: J7.2, U1.B5 (BGPO2/GPIO102)
/MEC1723/CMP_STRAP: R50.1, R51.2, U1.K2 (GPIO207/ADC07[CMP_STRAP])
/MEC1723/CR_STRAP: R39.1, R40.2, U1.E8 (GPIO045/KS001/PWM2_ALT/ICT14[CR_STRAP])
/MEC1723/GPIO000: J7.1, U1.B3 (SYSPWR_PRES&VCI_IN3#/GPIO000/I2C11_SDA)
/MEC1723/GPIO002: J8.7, U1.M8 (GPIO002/PWM5/SHD_CS1#)
/MEC1723/GPIO003: J12.3, R21.1, U1.F5 (GPIO003/I2C00_SDA/SPI0_CS0#)
/MEC1723/GPIO004: J12.7, R22.1, U1.C6 (GPIO004/I2C00_SCL/SPI0_MOSI)
/MEC1723/GPIO007: J8.4, R29.1, U1.B12 (GPIO007/I2C03_SDA/PS2_CLK0B)
/MEC1723/GPIO010: J10.4, R30.1, U1.C10 (GPIO010/I2C03_SCL/PS2_DAT0B)
/MEC1723/GPIO011: J11.8, U1.J6 (GPIO011/nSMI_ALT/PWM4/ICT7)
/MEC1723/GPIO012: J8.2, R37.1, U1.N6 (GPIO012/I2C07_SDA/SLV_SPI_IO2/TOUT3)
/MEC1723/GPIO013: J8.8, R38.1, U1.M7 (GPIO013/I2C07_SCL/SLV_SPI_IO3/TOUT2)
/MEC1723/GPIO014: J3.8, U1.M9 (GPIO014/PWM6/SLV_SPI_IO1/GPTP_IN2)
/MEC1723/GPIO015: J12.4, U1.J7 (GPIO015/PWM7/ICT10)
/MEC1723/GPIO17: J6.1, U1.J8 (GPIO017/KSI0/UART0_DCD#/GTPP_IN5)
/MEC1723/GPIO020: J12.2, U1.L7 (GPIO020/KSI1)
/MEC1723/GPIO021: J3.7, U1.N9 (GPIO021/KSI2)
/MEC1723/GPIO022: J11.4, U1.E2 (GPIO022/GPSPI_IO3/GPTP_IN4/32kHz_OUT_ALT)
/MEC1723/GPIO025: J5.8, U1.M12 (GPIO025/nEMI_INT/UART_CLK/UART1_RI#/TIN0)
/MEC1723/GPIO026: J5.7, U1.N13 (GPIO026/KSI3/UART0_DTR#/I2C12_SDA/TIN1)
/MEC1723/GPIO027: J6.2, U1.K11 (GPIO027/KSI4/UART0_DSR#/I2C12_SCL/TIN2)
/MEC1723/GPIO030: J6.4, U1.J9 (GPIO030/KSI5/I2C10_SDA/TIN3)
/MEC1723/GPIO031: J2.8, U1.M11 (GPIO031/KSI6/GPTP_OUT1)
/MEC1723/GPIO032: J6.3, U1.L10 (GPIO032/KSI7/GPTP_OUT0/UART0_RI#)
/MEC1723/GPIO034: J10.8, R24.1, U1.H12 (GPIO034/GPSPI_IO2/RC_ID1/SPI0_CLK)
/MEC1723/GPIO036: J10.7, R23.1, U1.H13 (GPIO036/RC_ID2/SPI0_MISO)
/MEC1723/GPIO040: J2.2, U1.M10 (GPIO040/GPTP_OUT2/KSO00)
/MEC1723/GPIO043: J5.4, U1.J13 (GPIO043/SB-TSI_CLK)
/MEC1723/GPIO046: J9.3, U1.E9 (GPIO046/KS002/ICT11/BCM1_DAT)
/MEC1723/GPIO047: J5.2, U1.F13 (GPIO047/KS003/PWM3_ALT/ICT13/BCM1_CLK)
/MEC1723/GPIO052: J6.8, U1.L8 (GPIO052/ICT2_TACH2)
/MEC1723/GPIO053: J5.9, U1.M13 (GPIO053/PWM0/SLV_SPI_MSTR_INT/GPWM0)
/MEC1723/GPIO054: J5.10, U1.L12 (GPIO054/PWM1/SLV_SPI_SCLK/GPWM1)
/MEC1723/GPIO100: J12.8, U1.H7 (GPIO100/nEC_SCI_ALT/ICT6)
/MEC1723/GPIO107: J3.1, U1.L13 (GPIO107/nSMI/KSO04/I2C10_SCL)
/MEC1723/GPIO112: J3.3, U1.K13 (GPIO112/KSO05(DSW_PWRGD))
/MEC1723/GPIO113: J2.9, U1.J11 (GPIO113/KSO06/ICT9)
/MEC1723/GPIO114: J10.10, U1.H9 (GPIO114/PS2_CLK0A/nEC_SCI)
/MEC1723/GPIO115: J2.10, U1.N12 (GPIO115/PS2_DAT0A)
/MEC1723/GPIO120: J3.2, U1.K12 (GPIO120/KSO07/UART1_DTR#)
/MEC1723/GPIO121: J5.1, U1.F12 (GPIO121/PVT_I00/KS008)
/MEC1723/GPIO122: J7.10, U1.E11 (GPIO122/PVT_I01/KS009)
/MEC1723/GPIO123: J2.7, U1.E12 (GPIO123/PVT_I02/KS010)
/MEC1723/GPIO124: J9.4, U1.C11 (GPIO124/PVT_CS#/KS011/ICT12/GPTP_OUT6)
/MEC1723/GPIO125: J9.8, U1.D11 (GPIO125/PVT_CLK/KS012/GPTP_OUT5)
/MEC1723/GPIO127: J9.7, U1.D13 (GPIO127/A20M/UART1_RTS#/UART0_CTS#_ALT)
/MEC1723/GPIO130: J8.9, R25.1, U1.N8 (GPIO130/I2C01_SDA/SLV_SPI_IO0/TOUT1)
/MEC1723/GPIO131: J8.3, R26.1, U1.N7 (GPIO131/I2C01_SCL/SLV_SPI_CS#/TOUT0)
/MEC1723/GPIO132: J2.4, R35.1, U1.N11 (GPIO132/I2C06_SDA/KSO16)
/MEC1723/GPIO135: J2.3, U1.E13 (GPIO035/PWM8/CTOUT1/ICT15/LED3)
/MEC1723/GPIO140: J8.1, R36.1, U1.L11 (GPIO140/I2C06_SCL/ICT5/KSO17)
/MEC1723/GPIO141: J12.9, R33.1, U1.B7 (GPIO141/I2C05_SDA/SPI1_CLK/UART0_DCD#_A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)
/MEC1723/GPIO142: J12.1, R34.1, U1.F7 (GPIO142/I2C05_SCL/SPI1_MOSI/UART0_DSR#_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)
/MEC1723/GPIO143: J7.4, R31.1, U1.A7 (GPIO143/I2C04_SDA/UART0_CTS#/SPI1_MISO/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)
/MEC1723/GPIO144: J10.3, R32.1, U1.E7 (GPIO144/I2C04_SCL/UART0_RTS#/SPI1_CS#/U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)
/MEC1723/GPIO151: J6.7, U1.L9 (GPIO151/ICT4/KSO15)
/MEC1723/GPIO152: J3.10, U1.N10 (GPIO152/KSO14/GPTP_OUT3/I2C07_SDA_ALT)
/MEC1723/GPIO153: J9.9, U1.C12 (GPIO153/LED2)
/MEC1723/GPIO154: J9.1, R27.1, U1.A12 (GPIO154/I2C02_SDA/CPU_C10)
/MEC1723/GPIO155: J10.9, R28.1, U1.C9 (GPIO155/I2C02_SCL(SYSPWR_VALID))
/MEC1723/GPIO156: J2.1, U1.A13 (GPIO156/LED0)
/MEC1723/GPIO157: J9.2, U1.B13 (GPIO157/LED1)
/MEC1723/GPIO175: J9.10, U1.C13 (GPIO175/CMP_VOUT1/PWM8_ALT)
/MEC1723/GPIO222: J12.10, U1.L5 (GPIO222/PROCHOT_IN#_ALT)
/MEC1723/GPIO224: J11.9, U1.A11 (GPIO244/UART_CLK_ALT/PWROK_ALT)
/MEC1723/GPIO240: J5.3, U1.G13 (GPIO240)
/MEC1723/GPIO241: J11.1, U1.B8 (GPIO241/CMP_VOUT0/PWM0_ALT)
/MEC1723/GPIO242: J11.3, U1.A10 (GPIO242/VCC_PWRGD_ALT)
/MEC1723/GPIO243: J7.9, U1.C8 (GPIO243/GPSPI_I01)
/MEC1723/GPIO245: J3.9, U1.B11 (GPIO245/GPSPI_I00)
/MEC1723/GPIO246: J11.7, U1.B10 (GPIO246/PWRGD_S0iX_ALT2/CTOUT1_ALT)
/MEC1723/GPIO254: J7.8, U1.B9 (GPIO254)
/MEC1723/PECI_DAT: J3.4, U1.J12 (GPIO042/PECI_DAT/SB-TSI_DAT)
/MEC1723/PWRGD_S0iX: J10.2, R9.1, U1.F2 (GPIO226/PWRGD_S0iX/CMP_VREF0)
/MEC1723/SLP_S0#: J11.2, U1.J5 (GPIO064/SLP_S0#)
/MEC1723/UART_BSTRAP: R48.1, R49.2, U1.D12 (GPIO126/PVT_I03/KS013[UART_BSTRAP])
/MEC1723/VCI_OUT2: J7.3, U1.C5 (VCI_OUT2)
/MEC1723/VCI_OVRD_IN: J10.1, U1.F1 (VCI_OVRD_IN)
/MEC1723/nRESET_IN: C7.2, R17.2, R18.1, U1.D3 (nRESET_IN)
/MEC1723/~RSMRST: R54.2, U1.B6 (GPIO255/UART1_RX_ALT/UART1_DSR#)
/MEC1723/~VCI_IN0(EMDRST_IN): C3.2, R13.2, R15.1, U1.E6 (VCI_IN0#(EMDRST_IN))
GND: C1.1, C2.1, C3.1, C4.1, C5.1, C6.1, C7.1, C8.1, C9.1, C10.1, C11.1, C12.1, C13.1, C14.1, C15.1, C16.1, J2.5, J2.6, J3.5, J3.6, J4.5, J4.6, J5.5, J5.6, J6.5, J6.6, J7.5, J7.6, J8.5, J8.6, J9.5, J9.6, J10.5, J10.6, J11.5, J11.6, J12.5, J12.6, R40.1, R44.1, R49.1, R51.1, R53.1, R54.1, SW1.4, SW2.4, SW3.4, U1.B4 (VSS_ANALOG), U1.F6 (VSS), U1.G3 (VSS), U1.H5 (VSS), U1.H11 (GPIO044/VREF_VTT), U1.K1 (VSS_ADC), U1.[F6,G3,H5] (VSS); also elsewhere on the board
unnamed: C1.2, R9.2, R10.2, R11.1
unnamed: D1.2 (A), R16.2
unnamed: C12.2, D1.1 (C), D2.1 (C), U1.E5 (VBAT)
unnamed: R11.2, SW1.2
unnamed: R15.2, SW2.2
unnamed: R18.2, SW3.2
unnamed: R45.1, U1.D1 (GPIO057/VCC_PWRGD/CMP_VIN0)
unnamed: C5.2, R14.2, U1.G2 (VREF_ADC)
unnamed: C16.2, U1.H1 (VR_CAP)
unnamed: C4.2, C6.2, R12.2, U1.G5 (VTR1)
unnamed: C8.2, R19.2, U1.H8 (VTR2)
unnamed: C9.2, R20.2, U1.H6 (VTR3)
unnamed: C14.2, R42.2, U1.G6 (VTR_ANALOG)
unnamed: C13.2, R41.2, U1.E1 (VTR_PLL)
unnamed: C15.2, R43.2, U1.G1 (VTR_REG)
unnamed: C10.2, U1.A3 (XTAL1), Y1.2
unnamed: C11.2, U1.A1 (XTAL2), Y1.1
unnamed: R46.1, U1.A6 (VCI_IN1#/GPIO162)
unnamed: R47.1, U1.C4 (VCI_IN2#/GPIO161)

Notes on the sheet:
Boot Source Select Strap: - 1(R3003 not mounted)=Use the shared SPI pins for boot - 0(R3003 mounted)=Use the eSPI Flash Channel for boot
SPI Flash used - ~{RSMRST} signal can be on any GPIO
I2C channels: 01-07
C3001 max. ESR = 100mohm
PIN BREAKOUT
PVT Flash
JTAG_STRAP
BUTTONS

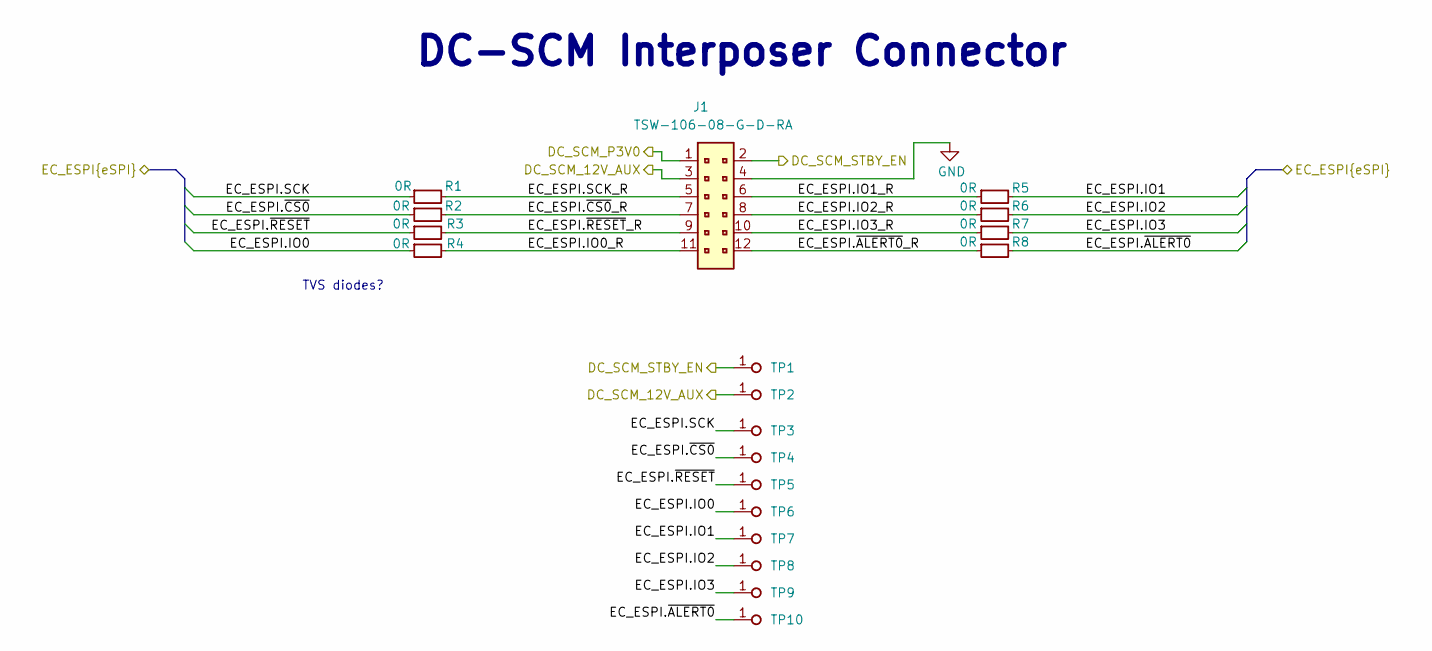
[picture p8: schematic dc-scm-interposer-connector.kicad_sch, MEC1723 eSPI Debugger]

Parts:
J1: PinHeader_2x6_P2.54mm_Drill1.1mm_Horizontal; PinHeader_2x6_P2.54mm_Drill1.1mm_Horizontal_ALT; MPN TSW-106-08-G-D-RA
R1, R2, R3, R4, R5, R6, R7, R8: R_0R_0402; R_0402_1005Metric; MPN ERJ2GE0R00X
TP1, TP2: TP_1mm_SMD; TP_SMD_1mm
TP3, TP4, TP5, TP6, TP7, TP8, TP9, TP10: TP_0.75mm_SMD; TP_SMD_0.75mm

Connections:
+3V0: J1.1; also elsewhere on the board
/DC-SCM Interposer connector/DC_SCM_12V_AUX: J1.3, TP2.1 (1_1); also elsewhere on the board
/DC-SCM Interposer connector/DC_SCM_STBY_EN: J1.2, TP1.1 (1_1); also elsewhere on the board
/DC-SCM Interposer connector/EC_ESPI.IO0: R4.1, TP6.1 (1_1); also elsewhere on the board
/DC-SCM Interposer connector/EC_ESPI.IO0_R: J1.11, R4.2
/DC-SCM Interposer connector/EC_ESPI.IO1: R5.2, TP7.1 (1_1); also elsewhere on the board
/DC-SCM Interposer connector/EC_ESPI.IO1_R: J1.6, R5.1
/DC-SCM Interposer connector/EC_ESPI.IO2: R6.2, TP8.1 (1_1); also elsewhere on the board
/DC-SCM Interposer connector/EC_ESPI.IO2_R: J1.8, R6.1
/DC-SCM Interposer connector/EC_ESPI.IO3: R7.2, TP9.1 (1_1); also elsewhere on the board
/DC-SCM Interposer connector/EC_ESPI.IO3_R: J1.10, R7.1
/DC-SCM Interposer connector/EC_ESPI.SCK: R1.1, TP3.1 (1_1); also elsewhere on the board
/DC-SCM Interposer connector/EC_ESPI.SCK_R: J1.5, R1.2
/DC-SCM Interposer connector/EC_ESPI.~ALERT0: R8.2, TP10.1 (1_1); also elsewhere on the board
/DC-SCM Interposer connector/EC_ESPI.~ALERT0_R: J1.12, R8.1
/DC-SCM Interposer connector/EC_ESPI.~CS0: R2.1, TP4.1 (1_1); also elsewhere on the board
/DC-SCM Interposer connector/EC_ESPI.~CS0_R: J1.7, R2.2
/DC-SCM Interposer connector/EC_ESPI.~RESET: R3.1, TP5.1 (1_1); also elsewhere on the board
/DC-SCM Interposer connector/EC_ESPI.~RESET_R: J1.9, R3.2
GND: J1.4; also elsewhere on the board

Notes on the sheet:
DC-SCM Interposer Connector
TVS diodes?

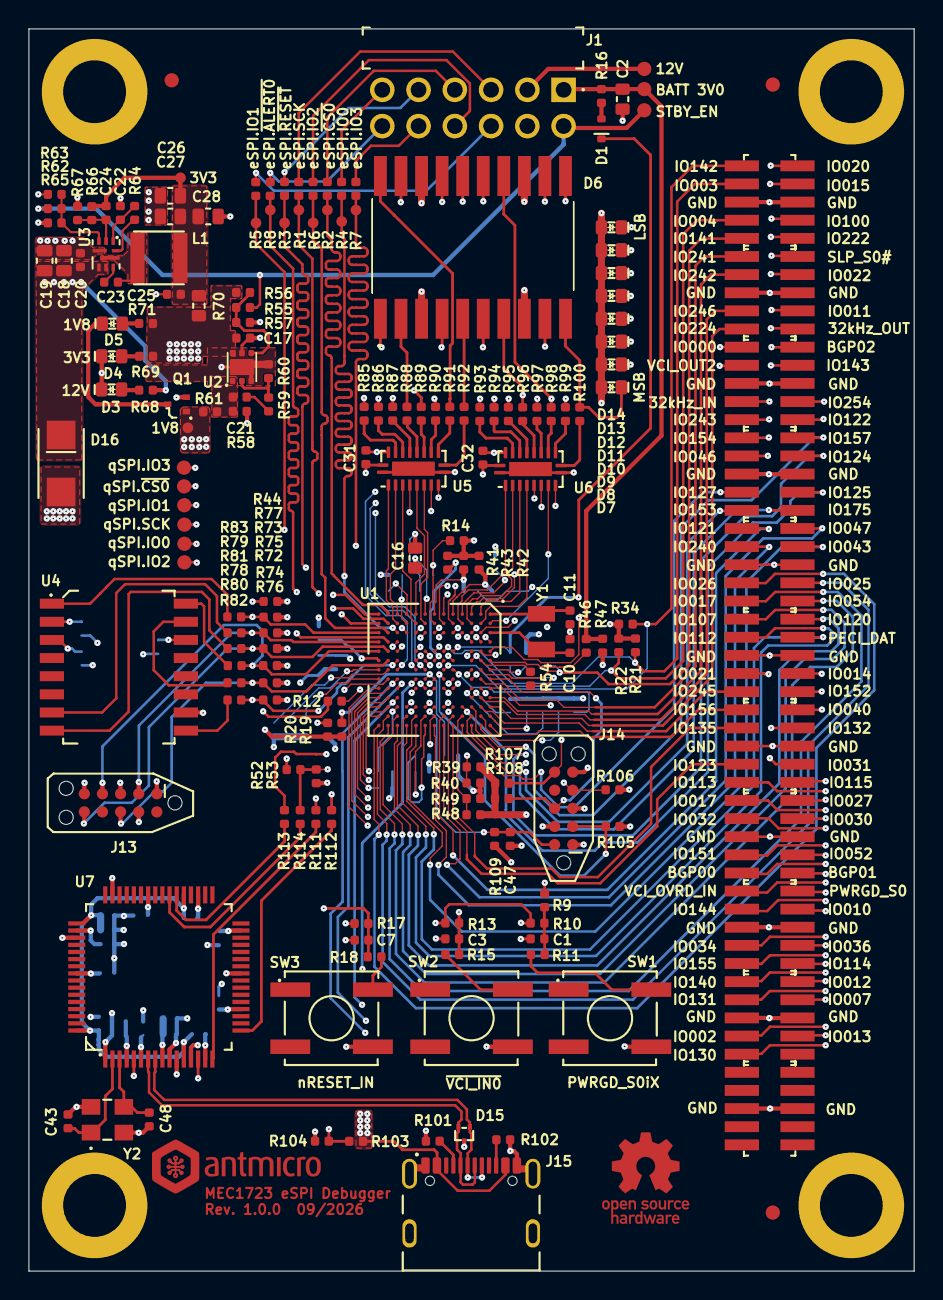
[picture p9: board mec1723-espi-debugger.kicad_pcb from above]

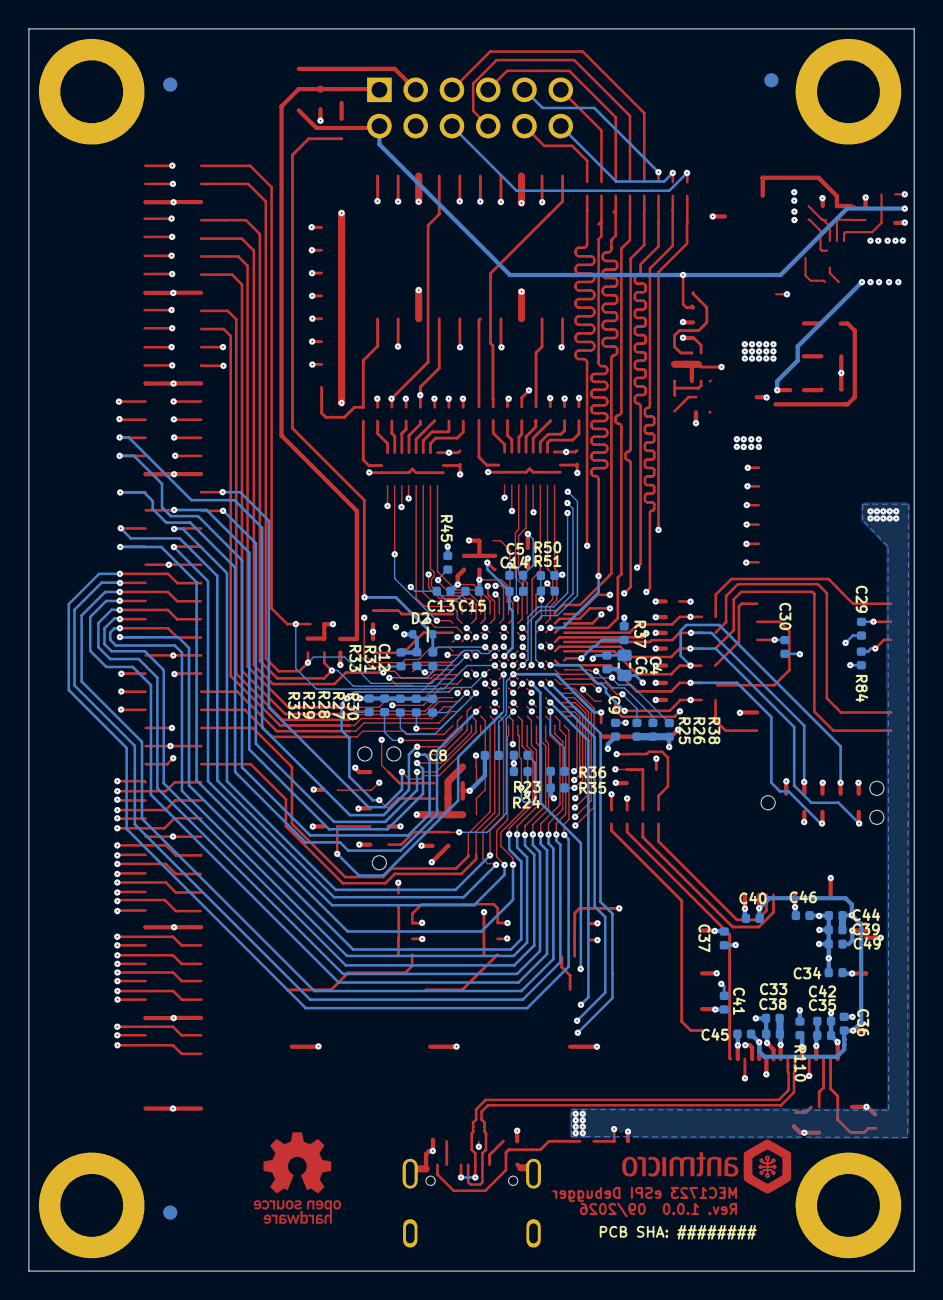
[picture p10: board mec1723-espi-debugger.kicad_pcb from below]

Board: 8 copper layers, 62.0 x 87.0 mm, 239 parts (53 on the bottom side), 225 nets.

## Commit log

2026-08-17 Add .gitignore, create empty project
    [dc-scm-server-integration-espi-adapter.kicad_pcb, dc-scm-server-integration-espi-adapter.kicad_sch]
2026-08-17 Add hierarchical pages, add notes
    [connectors.kicad_sch, dc-scm-interposer-connector.kicad_sch, dc-scm-server-integration-espi-adapter.kicad_pcb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]
2026-08-18 [#103224] Add QSPI Flash section, add .ci.yml
    [dc-scm-server-integration-espi-adapter.kicad_sch, flash.kicad_sch, mec1723.kicad_sch]
2026-08-18 [#103224] Add page template
    [dc-scm-server-integration-espi-adapter.kicad_sch]
2026-08-18 [#103224] Add JTAG connector, add 2nd QSPI flash in co-layout, add Antmicro and OSH logos
    [connectors.kicad_sch, dc-scm-server-integration-espi-adapter.kicad_sch, flash.kicad_sch]
2026-08-18 [#103224] Add dc-scm interposer connectors, fix typo in JTAG nametags
    [dc-scm-interposer-connector.kicad_sch]
2026-08-18 [#103224] Add MEC1723 IC, JTAG connections, eSPI connections, QSPI connections, fix typo in UART
    [connectors.kicad_sch, dc-scm-interposer-connector.kicad_sch, dc-scm-server-integration-espi-adapter.kicad_sch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]
2026-08-19 [#103224] Add decoupling, add reset, add notes
    [dc-scm-interposer-connector.kicad_sch, mec1723.kicad_sch]
2026-08-19 [#103224] Add 7-segment display section, add battery cicruit
    [dc-scm-interposer-connector.kicad_sch, dc-scm-server-integration-espi-adapter.kicad_pcb, dc-scm-server-integration-espi-adapter.kicad_sch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]
2026-08-19 [#103224] Add power section schematic
    [power.kicad_sch]
2026-08-19 [#103224] Change buffer ICs, change JTAG connector, move BSS_STRAP resistors to MEC1723 sheet
    [connectors.kicad_sch, dc-scm-interposer-connector.kicad_sch, dc-scm-server-integration-espi-adapter.kicad_sch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]
2026-08-19 [#103224] Route 7segment buffers, fix minor typos,add TODO list
    [dc-scm-server-integration-espi-adapter.kicad_sch, flash.kicad_sch, port80-leds.kicad_sch]
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2026-08-20 [#103224] Divide 7SEG bus into 2, rename JTAG connector pins
    [connectors.kicad_sch, dc-scm-interposer-connector.kicad_sch, dc-scm-server-integration-espi-adapter.kicad_sch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]
2026-08-20 [#103224] Add root schematic connections, add EMDRST button, add 1u decoupling capacitors, connect UART, add fiducials
    [connectors.kicad_sch, dc-scm-server-integration-espi-adapter.kicad_sch, flash.kicad_sch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]
2026-08-20 [#103436] Start adding strap and configuration pins needed for power up
    [mec1723.kicad_sch]
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2026-08-23 [#103224] Add strapping pins, check for signals needed to boot, add breakout connectors, add testpoints
    [flash.kicad_sch, mec1723.kicad_sch]
2026-08-23 [#103224] Add pullup resistors to VCI_IN#, add pulldown to nRSMRST, add schottky diode on VBAT
    [mec1723.kicad_sch]
2026-08-23 [#103224] Add UART1, added GND to breakout connectors, fix orientation of DC-SCM connector, delete unused notes
    [connectors.kicad_sch, dc-scm-interposer-connector.kicad_sch, dc-scm-server-integration-espi-adapter.kicad_sch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]
2026-08-23 [#103224] Add PCB file, import board setup, add board outline and user drawings
    [dc-scm-server-integration-espi-adapter.kicad_pcb]
2026-08-23 [#103224] Add notes to schematic, fix typos, fix gpio connections, bump date
    [dc-scm-server-integration-espi-adapter.kicad_pcb, dc-scm-server-integration-espi-adapter.kicad_sch, flash.kicad_sch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]
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2026-08-23 [#103224] port80-leds: swap H/L, add missing signal labels
    [port80-leds.kicad_sch]
2026-08-23 [#103224] power: set 3.3V DC-DC converter enable resistors as populated
    [power.kicad_sch]
2026-08-23 [#103224] flash: remove redundant pullup and decoupling
    Duplicated but not needed due to colayout
    [flash.kicad_sch]
2026-08-23 [#103224] connectors: fix JTAG bus
    [connectors.kicad_sch]
2026-08-24 [103224] Add USB with FT232RL, transfer elements onto PCB, start positioning elements
    [connectors.kicad_sch, dc-scm-server-integration-espi-adapter.kicad_pcb]
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2026-08-24 [#103696] Tweak the constrainss and trace width, place BGA vias
    [dc-scm-server-integration-espi-adapter.kicad_pcb]
2026-08-25 [#103696] Initial placement of all components, delete redundant testpoints
    [dc-scm-server-integration-espi-adapter.kicad_pcb, dc-scm-server-integration-espi-adapter.kicad_sch, mec1723.kicad_sch]
2026-08-25 [#103696] Add 0 ohm resistors to power rails on the scheatic, changed C7001 from 10uF to 1uF
    [connectors.kicad_sch, dc-scm-server-integration-espi-adapter.kicad_pcb, flash.kicad_sch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]
2026-08-25 [#103696] Changed PCB orientation to vertical, changed 7seg display orientation, add 0ohm resistors on power rails (pcb)
    [dc-scm-server-integration-espi-adapter.kicad_pcb]
2026-08-25 [#103697] Change key sectors placement (DC-DC, 7seg, Flash, FTDI), Change buttons, Change DC-SCM connector to angled header
    [dc-scm-interposer-connector.kicad_sch, dc-scm-server-integration-espi-adapter.kicad_pcb, mec1723.kicad_sch]
2026-08-25 [#103811] Replace FT232RL with FT2232H - unifinished
    [connectors.kicad_sch, dc-scm-interposer-connector.kicad_sch]
2026-08-26 [#103753] Fix issues according to the review, add FT2232 to the schematic
    [connectors.kicad_sch, dc-scm-interposer-connector.kicad_sch, dc-scm-server-integration-espi-adapter.kicad_pcb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]
2026-08-26 [#103753] Fix issues according to the review, add redundant LEDs, delete fp-lib-table
    [connectors.kicad_sch, dc-scm-server-integration-espi-adapter.kicad_pcb, dc-scm-server-integration-espi-adapter.kicad_sch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]
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2026-08-26 [#103696] Change redundant LED connections, place LEDs on PCB
    [dc-scm-server-integration-espi-adapter.kicad_pcb, dc-scm-server-integration-espi-adapter.kicad_sch, port80-leds.kicad_sch]
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2026-08-26 [#103753] Fixed issues according to the review
    [connectors.kicad_sch, dc-scm-server-integration-espi-adapter.kicad_pcb, port80-leds.kicad_sch]
2026-08-27 [#103697] Change redundant LED connections, start PCB layout
    [dc-scm-interposer-connector.kicad_sch, dc-scm-server-integration-espi-adapter.kicad_pcb, port80-leds.kicad_sch]
2026-08-27 [#103697] Route eSPI, route decoupling for FT2232 and MEC1723
    [dc-scm-server-integration-espi-adapter.kicad_pcb]
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2026-08-27 [#103697] Route qSPI, 7seg, and 1V8 plane, fix issues
    [dc-scm-server-integration-espi-adapter.kicad_pcb, mec1723.kicad_sch]
2026-08-27 [#103697] Reenumerate the entire schematic, rerouting eSPI to maintain bigger gap between traces, rerouting the LDO
    [connectors.kicad_sch, dc-scm-interposer-connector.kicad_sch, dc-scm-server-integration-espi-adapter.kicad_pcb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]
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2026-08-27 [#103697] pcb: fix MEC1723N-B0-I/SZ ball size
    Datasheets states 0.25mm pad size
    [dc-scm-server-integration-espi-adapter.kicad_pcb]
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2026-08-27 [#103697] pcb: reduce GND pur min width and spacing to 0.125mm
    [dc-scm-server-integration-espi-adapter.kicad_pcb]
2026-08-28 [#103697] Fix decoupling nets, route JTAG, buttons, UART, power
    [dc-scm-server-integration-espi-adapter.kicad_pcb, mec1723.kicad_sch]
2026-08-28 [#103697] Route 7seg, fix power rails, leaving GPIO disconnected
    [dc-scm-server-integration-espi-adapter.kicad_pcb, mec1723.kicad_sch]
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2026-09-01 [#103697] Clean DRC errors, board cleanup, aesthetic changes
    [dc-scm-server-integration-espi-adapter.kicad_pcb]
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2026-09-01 [#103697] switch dc-dc for TPS566231PRQFR, eSPI length tuning, change zone clearance, fix clearance problems
    [connectors.kicad_sch, dc-scm-server-integration-espi-adapter.kicad_pcb, flash.kicad_sch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]
2026-09-01 [#103697] fix eSPI length tuning, add msb and lsb indicators for LED
    [dc-scm-server-integration-espi-adapter.kicad_pcb]
2026-09-02 [#103697] Change LDO layout, add power from USB, fix length tuning, change In4.Cu to GND/SIG and In5.Cu to 3V3, cleanup the design
    [connectors.kicad_sch, dc-scm-interposer-connector.kicad_sch, dc-scm-server-integration-espi-adapter.kicad_pcb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]
2026-09-02 [#103697] Fix via size of 7seg vias
    [dc-scm-server-integration-espi-adapter.kicad_pcb]
2026-09-02 [#103697] Change stackup - 35um to 18um for inner copper layers
    [dc-scm-server-integration-espi-adapter.kicad_pcb]
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2026-09-02 [#103697] pcb: move GPIO156 trace further from the tag-connect hole
    [mec1723-espi-debugger.kicad_pcb]
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2026-09-02 [#103697] pcb: route VBUS on bottom and In6 layers
    [mec1723-espi-debugger.kicad_pcb]
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2026-09-02 [#103697] pcb: resolve DRC
    [mec1723-espi-debugger.kicad_pcb]
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2026-09-09 Move stackup table to Fab, add board dimensions
    [mec1723-espi-debugger.kicad_pcb]
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2026-09-15 [#105108] Flip spacers to bottom layer
    [mec1723-espi-debugger.kicad_pcb]
2026-09-15 [#105108] Update README image with flipped spacers

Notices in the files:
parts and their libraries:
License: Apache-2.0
